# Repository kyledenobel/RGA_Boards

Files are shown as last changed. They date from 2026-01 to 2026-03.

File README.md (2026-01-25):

# RGA_Boards
PCB Board design and development for RGA (Recording Guitar Amplifier)

## Issues and Organization
After completing an issue for board design, please mark as resolved and mention your branch/merge and create another issue for fabrication with the milestone "All Boards Have Been Fabricated" linked to the issue.
Similarly, after fabrication is finished, make an issue for testing with the milestone "All Boards Have Been Tested" linked to the issue.

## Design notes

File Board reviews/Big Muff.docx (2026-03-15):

# Kyle

## Schematic

1) Need to change connector to analog controller

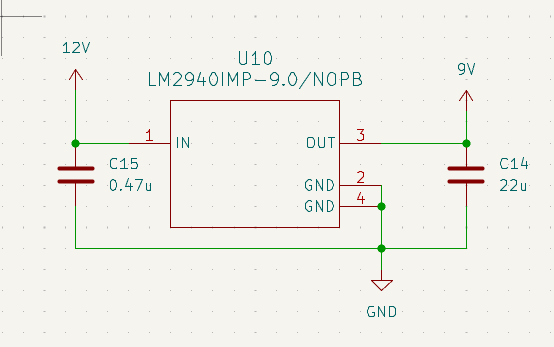
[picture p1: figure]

2) Can Big Muff run on 12 V? can save on component parts if we use 12 instead of 9

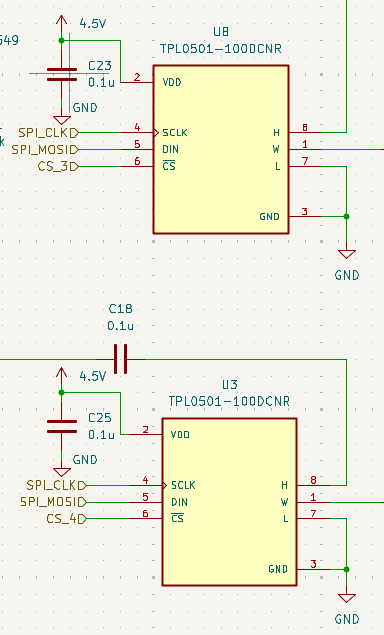
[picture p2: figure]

3) If these are to take more of one and less of another, we use just 1 CS and connect the analog signals opposite of each other. One is H->W->L and the other is L->W->H. When we send the same message, to both in this configuration, they will automatically be opposites of each other.

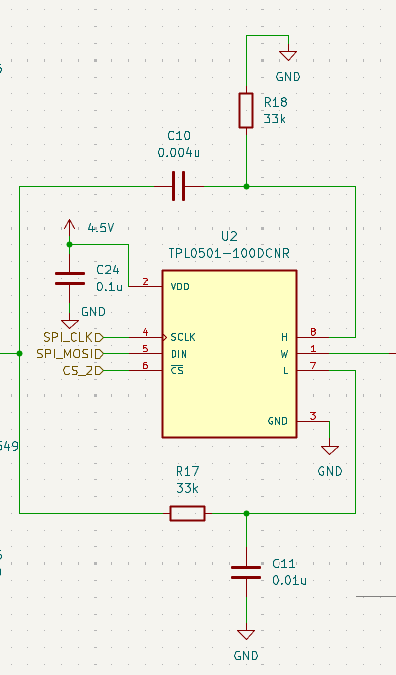
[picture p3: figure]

4) Is decoupling needed on the lower signal?

## Layout

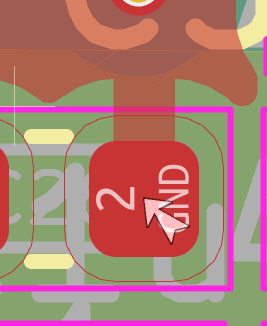
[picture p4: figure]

1) If we care about thermal relief

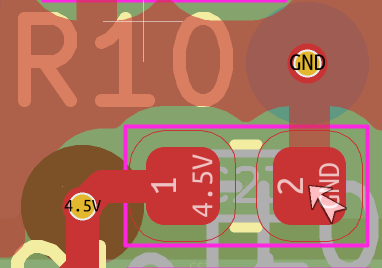
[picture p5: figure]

2) thermal relief

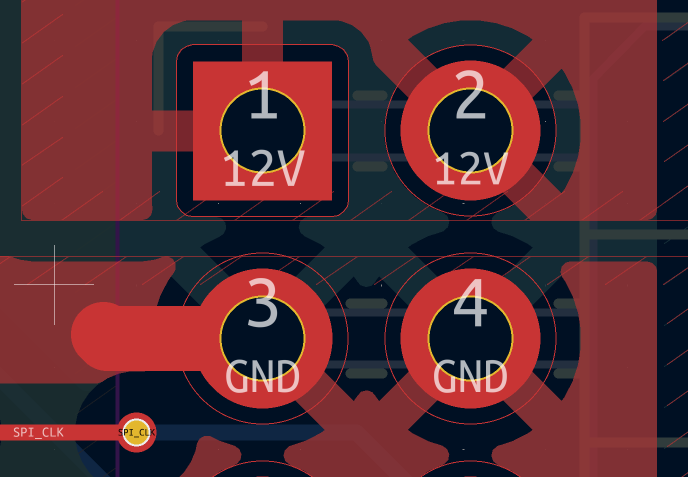
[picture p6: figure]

3) track just chilling. Not connected to anything.

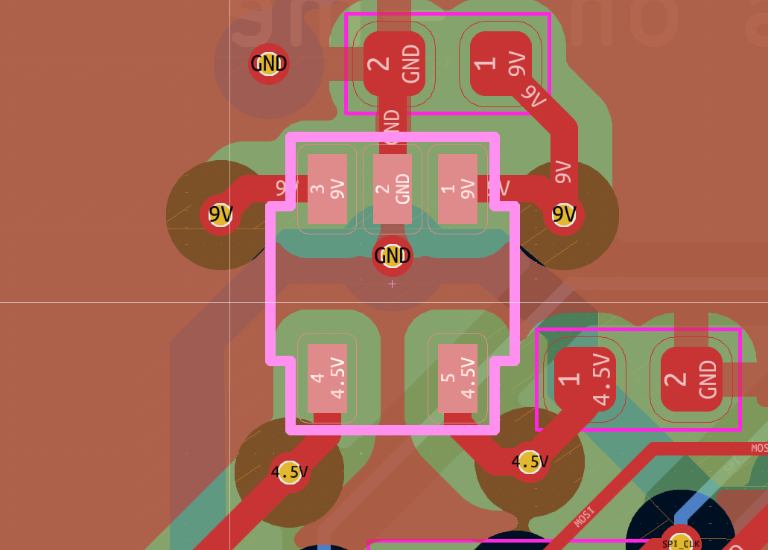
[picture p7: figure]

Gonna need way more vias for that 4.5V plane connection

Big Muff Review

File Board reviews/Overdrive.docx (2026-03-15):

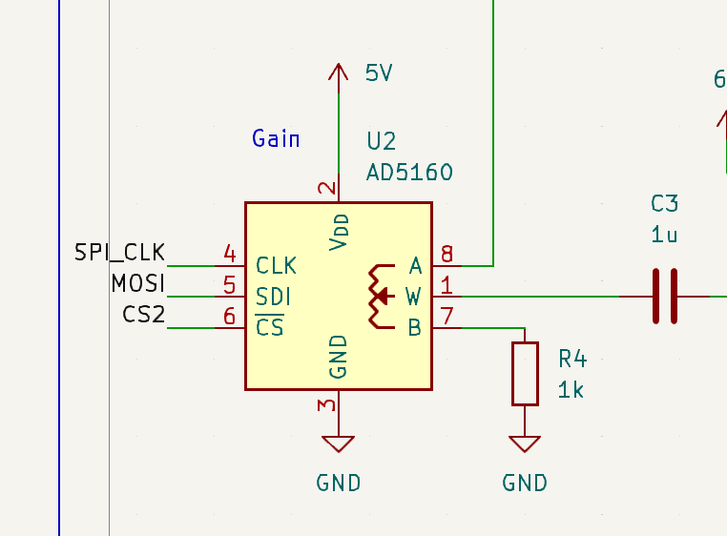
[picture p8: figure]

Add decoupling capacitors to U2 and U5

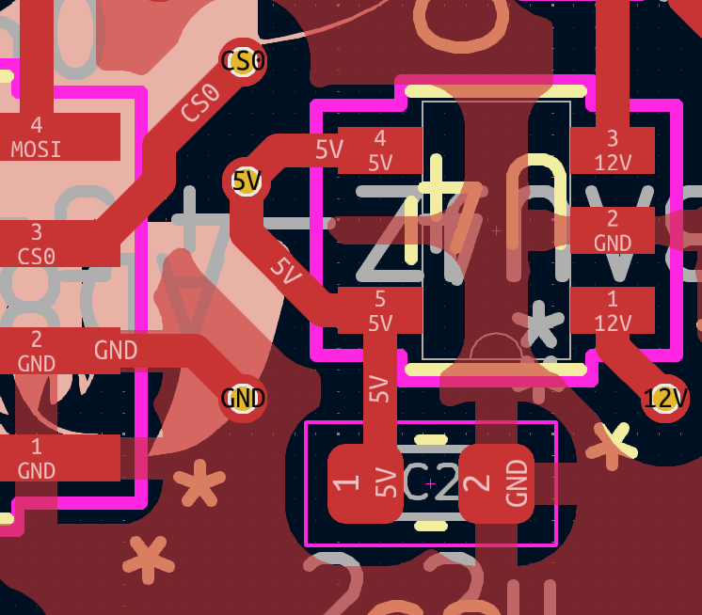
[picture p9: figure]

Add more vias to connect 5V on top layer to 5V plane on 3rd layer

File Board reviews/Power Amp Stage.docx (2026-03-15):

# Kyle

## Schematic

1) No Resistor Values??

## Layout

1) Any reason to flip GND and POWER planes for In2 and B planes? In2 has 24V and GND zones and B has -24V and GND zones. Why not make 1 a purely power and the other purely GND?

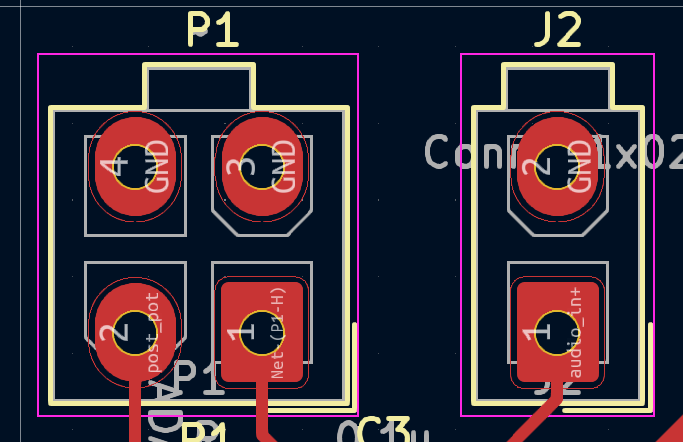
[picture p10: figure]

Ground should be bottom pins. Pins 1 and 2 on the left and Pin 1 on the right should be GND

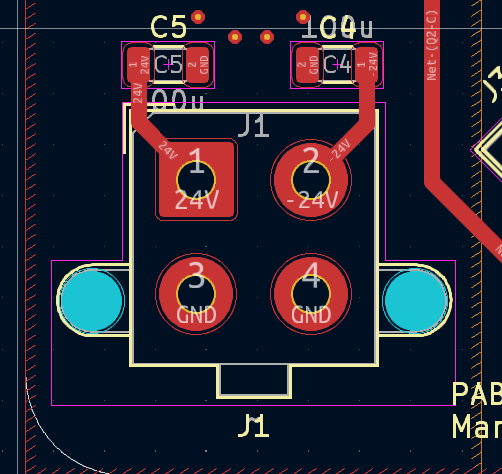
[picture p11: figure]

Same here

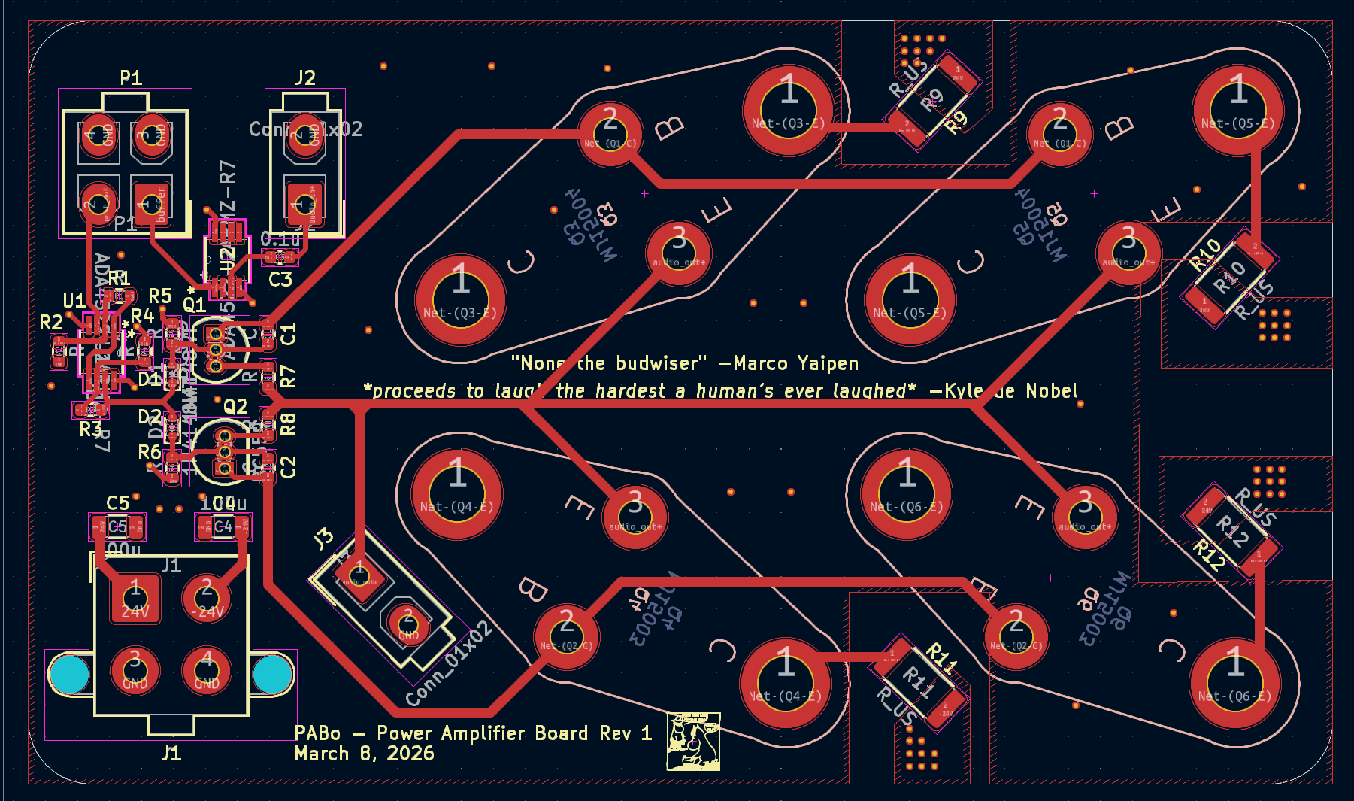
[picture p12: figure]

Moving the connector *might* improve signal quality, because it is now at the end of the signal githupath

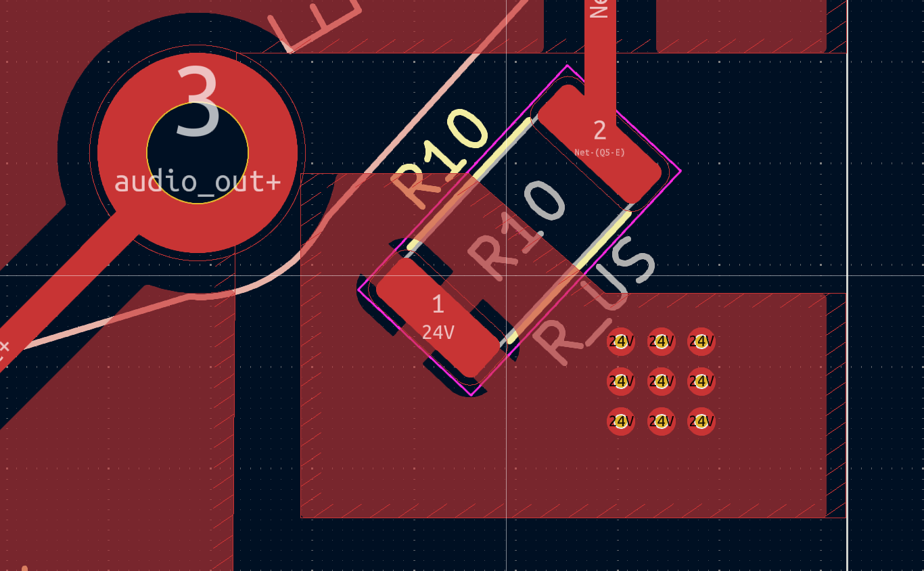
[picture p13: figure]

Thermal reliefs too small for high current carrying paths. Make the connections solid instead. Add more vias to connect the layers.

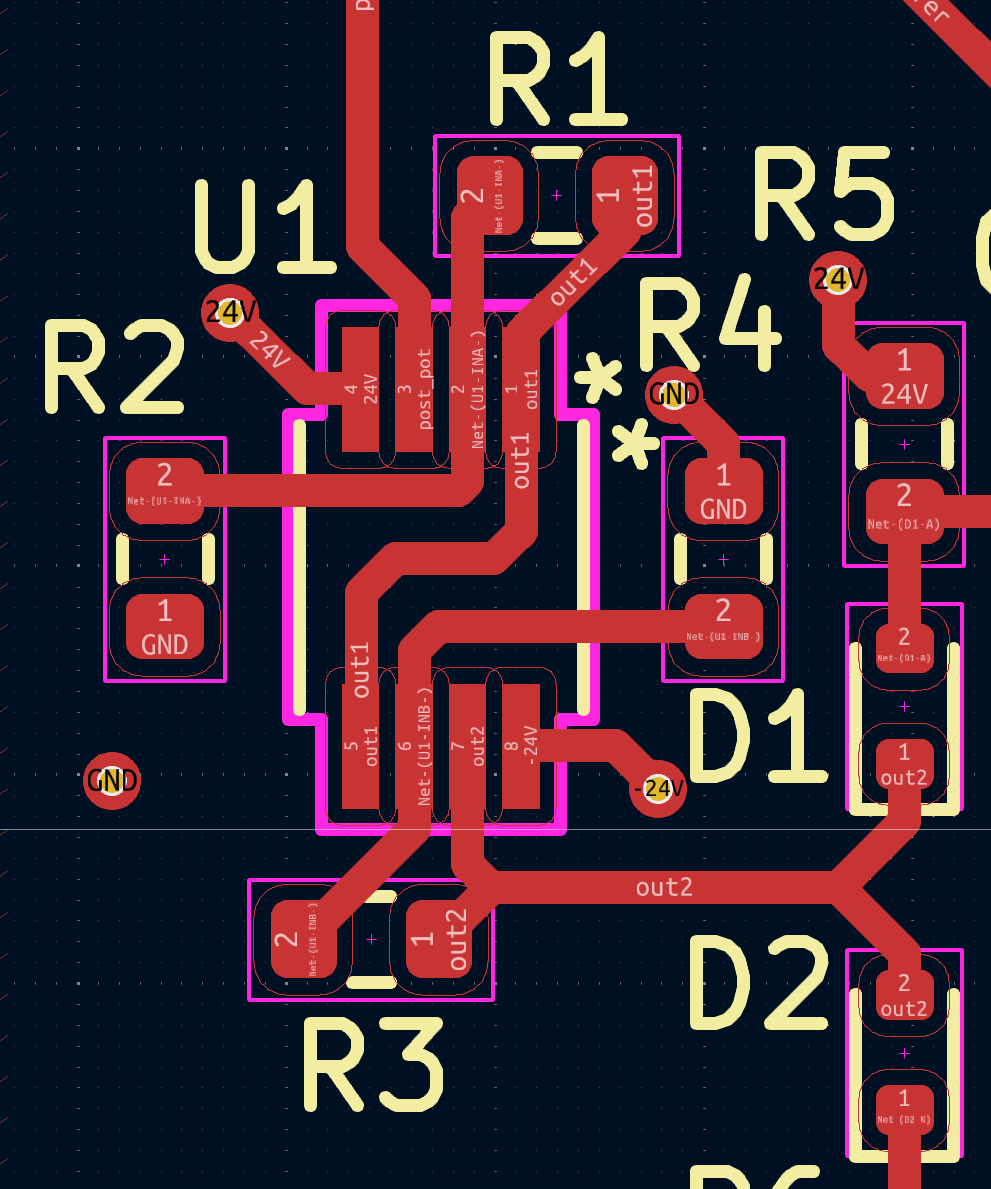
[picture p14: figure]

Move components

Power Amp Stage Review

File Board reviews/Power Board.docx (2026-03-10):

# Kyle

## Schematic

Not finished. Need +/- 24 V supply

## Layout

Power Board Review

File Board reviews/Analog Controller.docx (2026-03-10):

# Kyle

## Schematic Comments

No comments. Looks good.

## Layout Comments

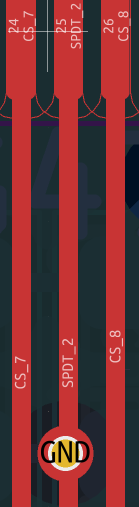
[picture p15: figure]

Shorted SPDT_2 to GND

Analog Controller Board Review

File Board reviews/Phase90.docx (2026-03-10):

# Kyle

## Layout

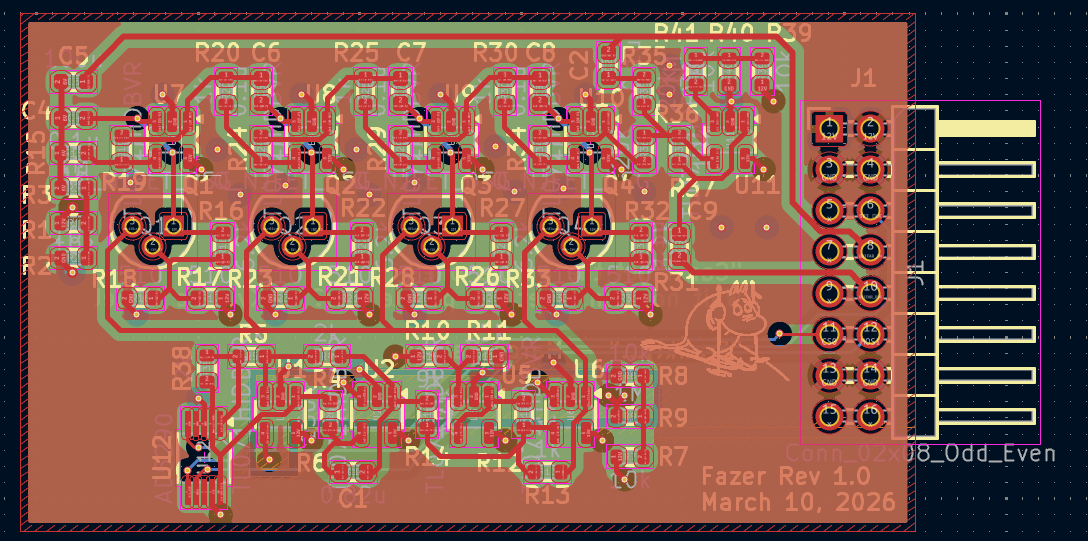
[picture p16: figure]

1) This won’t be able to slide into anything bc of how close things are to the edge. We might need to move the oscillator to the far left and shift the phase shifting down more towards the center of the board.
2) In general, there are a lot of clearance violations, and not all are due to footprints. I think that some routing could be redone to avoid these (there is definitely space to do so around some of these violations).

Phase 90 Review

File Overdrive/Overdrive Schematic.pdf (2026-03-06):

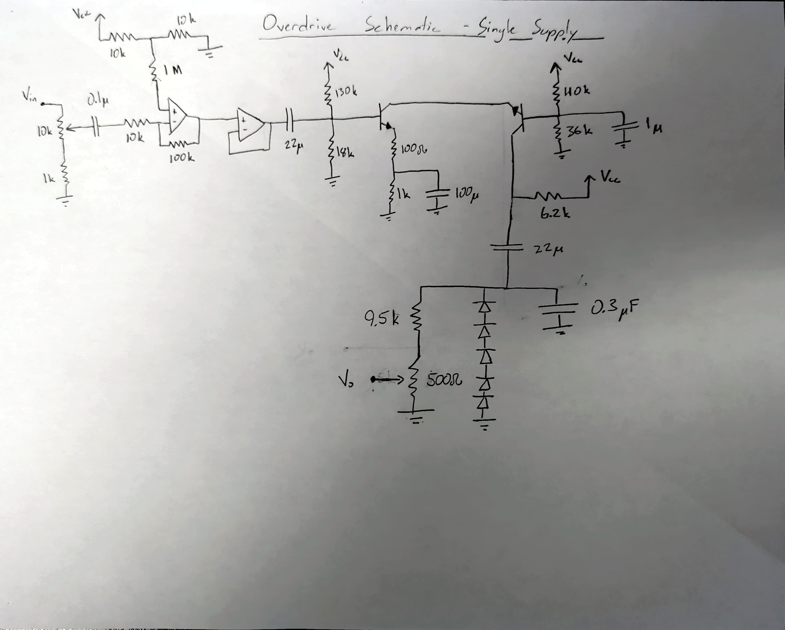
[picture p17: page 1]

q_5k

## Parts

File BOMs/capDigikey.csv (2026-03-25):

Index | Quantity | Part Number | Manufacturer Part Number | Description | Customer Reference | Available | Backorder | Unit Price | Extended Price USD
1 | 150 | 13-CC0603MPY5V9BB104CT-ND | CC0603MPY5V9BB104 | CAP CER 0.1UF 50V Y5V 0603 |  | 150 | 0 | 0.01990 | 2.99
2 | 10 | 399-C0603C103K5RACTUCT-ND | C0603C103K5RACTU | CAP CER 10000PF 50V X7R 0603 |  | 10 | 0 | 0.00900 | 0.09
3 | 10 | 399-C0603C471J5GACTUCT-ND | C0603C471J5GACTU | CAP CER 470PF 50V C0G/NP0 0603 |  | 10 | 0 | 0.04900 | 0.49
4 | 3 | 587-3170-1-ND | UMK107B7474KA-TR | CAP CER 0.47UF 50V X7R 0603 |  | 3 | 0 | 0.15000 | 0.45
5 | 10 | 490-7203-1-ND | GRM188R61E475KE11D | CAP CER 4.7UF 25V X5R 0603 |  | 10 | 0 | 0.03800 | 0.38
6 | 3 | 445-174426-1-ND | CGA3E3X7R1H334K080AB | CAP CER 0.33UF 50V X7R 0603 |  | 3 | 0 | 0.22000 | 0.66
7 | 3 | 13-CC0603KRX7R7BB824CT-ND | CC0603KRX7R7BB824 | CAP CER 0.82UF 16V X7R 0603 |  | 3 | 0 | 0.11000 | 0.33
8 | 10 | 399-C0603C102K5RACTUCT-ND | C0603C102K5RACTU | CAP CER 1000PF 50V X7R 0603 |  | 10 | 0 | 0.00900 | 0.09
9 | 10 | 1292-1542-1-ND | 0603N680J500CT | CAP CER 68PF 50V C0G/NP0 0603 |  | 10 | 0 | 0.02000 | 0.20
10 | 10 | 1276-1063-1-ND | CL10B473KB8NNNC | CAP CER 0.047UF 50V X7R 0603 |  | 10 | 0 | 0.02900 | 0.29
11 | 10 | 490-GCM1885C2A911FA16DCT-ND | GCM1885C2A911FA16D | CAP CER 910PF 100V C0G/NP0 0603 |  | 10 | 0 | 0.09000 | 0.90
12 | 10 | 490-9669-1-ND | GRM1885C1H472JA01D | CAP CER 4700PF 50V C0G/NP0 0603 |  | 10 | 0 | 0.06000 | 0.60
13 | 10 | 720-VJ0603Y681KXACW1BCCT-ND | VJ0603Y681KXACW1BC | CAP CER 680PF 50V X7R 0603 |  | 10 | 0 | 0.05000 | 0.50
14 | 10 | 399-C0603C221K5RACTUCT-ND | C0603C221K5RACTU | CAP CER 220PF 50V X7R 0603 |  | 10 | 0 | 0.04000 | 0.40
15 | 2 | 490-GRM21BR60G107ME11KCT-ND | GRM21BR60G107ME11K | CAP CER 100UF 4V X5R 0805 |  | 2 | 0 | 0.53000 | 1.06
16 | 12 | 490-12737-1-ND | GRM188R61E106MA73J | CAP CER 10UF 25V X5R 0603 |  | 12 | 0 | 0.14200 | 1.70
17 | 100 | 587-3247-1-ND | UMK107AB7105KA-T | CAP CER 1UF 50V X7R 0603 |  | 100 | 0 | 0.02900 | 2.90
18 | 10 | 490-10731-1-ND | GRM188R61E225KA12D | CAP CER 2.2UF 25V X5R 0603 |  | 10 | 0 | 0.04900 | 0.49
19 | 12 | 478-KGM15CR51C226MTCT-ND | 0603YD226MAT2A | CAP CER 22UF 16V X5R 0603 |  | 12 | 0 | 0.29700 | 3.56

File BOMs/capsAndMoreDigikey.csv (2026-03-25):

Index | Quantity | Part Number | Manufacturer Part Number | Description | Customer Reference | Available | Backorder | Unit Price | Extended Price USD
1 | 150 | 13-CC0603MPY5V9BB104CT-ND | CC0603MPY5V9BB104 | CAP CER 0.1UF 50V Y5V 0603 |  | 150 | 0 | 0.01990 | 2.99
2 | 10 | 399-C0603C103K5RACTUCT-ND | C0603C103K5RACTU | CAP CER 10000PF 50V X7R 0603 |  | 10 | 0 | 0.00900 | 0.09
3 | 10 | 399-C0603C471J5GACTUCT-ND | C0603C471J5GACTU | CAP CER 470PF 50V C0G/NP0 0603 |  | 10 | 0 | 0.04900 | 0.49
4 | 3 | 587-3170-1-ND | UMK107B7474KA-TR | CAP CER 0.47UF 50V X7R 0603 |  | 3 | 0 | 0.15000 | 0.45
5 | 10 | 490-7203-1-ND | GRM188R61E475KE11D | CAP CER 4.7UF 25V X5R 0603 |  | 10 | 0 | 0.03800 | 0.38
6 | 3 | 445-174426-1-ND | CGA3E3X7R1H334K080AB | CAP CER 0.33UF 50V X7R 0603 |  | 3 | 0 | 0.22000 | 0.66
7 | 3 | 13-CC0603KRX7R7BB824CT-ND | CC0603KRX7R7BB824 | CAP CER 0.82UF 16V X7R 0603 |  | 3 | 0 | 0.11000 | 0.33
8 | 10 | 399-C0603C102K5RACTUCT-ND | C0603C102K5RACTU | CAP CER 1000PF 50V X7R 0603 |  | 10 | 0 | 0.00900 | 0.09
9 | 10 | 1292-1542-1-ND | 0603N680J500CT | CAP CER 68PF 50V C0G/NP0 0603 |  | 10 | 0 | 0.02000 | 0.20
10 | 10 | 1276-1063-1-ND | CL10B473KB8NNNC | CAP CER 0.047UF 50V X7R 0603 |  | 10 | 0 | 0.02900 | 0.29
11 | 10 | 490-GCM1885C2A911FA16DCT-ND | GCM1885C2A911FA16D | CAP CER 910PF 100V C0G/NP0 0603 |  | 10 | 0 | 0.09000 | 0.90
12 | 10 | 490-9669-1-ND | GRM1885C1H472JA01D | CAP CER 4700PF 50V C0G/NP0 0603 |  | 10 | 0 | 0.06000 | 0.60
13 | 10 | 720-VJ0603Y681KXACW1BCCT-ND | VJ0603Y681KXACW1BC | CAP CER 680PF 50V X7R 0603 |  | 10 | 0 | 0.05000 | 0.50
14 | 10 | 399-C0603C221K5RACTUCT-ND | C0603C221K5RACTU | CAP CER 220PF 50V X7R 0603 |  | 10 | 0 | 0.04000 | 0.40
15 | 2 | 490-GRM21BR60G107ME11KCT-ND | GRM21BR60G107ME11K | CAP CER 100UF 4V X5R 0805 |  | 2 | 0 | 0.53000 | 1.06
16 | 12 | 490-12737-1-ND | GRM188R61E106MA73J | CAP CER 10UF 25V X5R 0603 |  | 12 | 0 | 0.14200 | 1.70
17 | 100 | 587-3247-1-ND | UMK107AB7105KA-T | CAP CER 1UF 50V X7R 0603 |  | 100 | 0 | 0.02900 | 2.90
18 | 10 | 490-10731-1-ND | GRM188R61E225KA12D | CAP CER 2.2UF 25V X5R 0603 |  | 10 | 0 | 0.04900 | 0.49
19 | 12 | 478-KGM15CR51C226MTCT-ND | 0603YD226MAT2A | CAP CER 22UF 16V X5R 0603 |  | 12 | 0 | 0.29700 | 3.56
20 | 10 | 846-1198-1-ND | SML-D13M8WT86 | LED GREEN DIFFUSED 1608 SMD |  | 10 | 0 | 0.13200 | 1.32
21 | 14 | 1N4148W-13FDICT-ND | 1N4148W-13-F | DIODE STANDARD 100V 150MA SOD123 |  | 14 | 0 | 0.06000 | 0.84
22 | 10 | 1N4148WTCT-ND | 1N4148WT | DIODE STANDARD 75V 200MA SOD523F |  | 10 | 0 | 0.06900 | 0.69
23 | 2 | 36-3568-ND | 3568 | FUSE HOLDER BLADE 500V 30A PCB |  | 2 | 0 | 1.25000 | 2.50
24 | 25 | WM3800-ND | 0039281023 | CONN HEADER VERT 2POS |  | 25 | 0 | 0.48300 | 12.08
25 | 25 | WM3700-ND | 0039012020 | CONN RCPT HSG 2POS DUAL |  | 25 | 0 | 0.20000 | 5.00
26 | 6 | S7111-ND | PPPC082LFBN-RC | CONN HDR 16POS 0.1 GOLD PCB |  | 6 | 0 | 0.85000 | 5.10
27 | 10 | WM16836-ND | 0768290102 | CONN HEADER VERT 2POS |  | 10 | 0 | 0.88700 | 8.87
28 | 10 | WM10385-ND | 1716920102 | CONN RCPT HSG 2POS MEGA-FIT |  | 10 | 0 | 0.34900 | 3.49
29 | 2 | WM4713-ND | 0430451812 | CONN HEADER VERT 18POS 3MM |  | 2 | 0 | 1.95000 | 3.90
30 | 4 | WM26557-ND | 2068320801 | CONN HEADER VERT 8POS 3MM |  | 4 | 0 | 1.98000 | 7.92
31 | 4 | WM26545-ND | 2064610800 | CONN RCPT HSG 8POS 3.00MM |  | 4 | 0 | 0.60000 | 2.40
32 | 1 | 1951-2505-ND | TMV 1205D | DC DC CONVERTER +/-5V 1W |  | 1 | 0 | 6.40000 | 6.40
33 | 2 | 945-R-78K5.0-0.5-ND | R-78K5.0-0.5 | 0.5A DC/DC-CONVERTER 'INNOLINE' |  | 2 | 0 | 2.79000 | 5.58
34 | 1 | 1866-3063-ND | IRM-60-12 | AC/DC CONVERTER 12V 60W |  | 1 | 0 | 15.00000 | 15.00
35 | 10 | 4878-BC549CCT-ND | BC549C | TRANS NPN 30V 0.1A TO-92 |  | 10 | 0 | 0.08300 | 0.83
36 | 2 | 4878-BC559CCT-ND | BC559C | TRANS PNP 30V 0.1A TO-92 |  | 2 | 0 | 0.14000 | 0.28

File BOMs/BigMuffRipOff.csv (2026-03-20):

Reference | Qty | Value | DNP | Exclude from BOM | Exclude from Board | Footprint | Datasheet
C1,C3,C4,C6,C7,C8,C12,C13,C17,C18,C21,C22,C23,C24,C25,C26 | 16 | 0.1u |  |  |  | Capacitor_SMD:C_0603_1608Metric | ~
C2,C5,C9 | 3 | 470p |  |  |  | Capacitor_SMD:C_0603_1608Metric | ~
C10 | 1 | 0.004u |  |  |  | Capacitor_SMD:C_0603_1608Metric | ~
C11 | 1 | 0.01u |  |  |  | Capacitor_SMD:C_0603_1608Metric | ~
C14,C16,C27 | 3 | 22u |  |  |  | Capacitor_SMD:C_0603_1608Metric | ~
C15 | 1 | 0.47u |  |  |  | Capacitor_SMD:C_0603_1608Metric | ~
C19,C20 | 2 | 2.2u |  |  |  | Capacitor_SMD:C_0603_1608Metric | ~
C28,C29,C30,C31 | 4 | 1u |  |  |  | Capacitor_SMD:C_0603_1608Metric | ~
CR3,CR4 | 2 | 1N4148W-13-F |  |  |  | 284867-E-footprint:SOD123_DIO | 1N4148W-13-F
J1 | 1 | Conn_02x08_Odd_Even |  |  |  | Connector_PinHeader_2.54mm:PinHeader_2x08_P2.54mm_Horizontal | ~
Q1,Q2,Q3,Q4 | 4 | BC549 |  |  |  | Package_TO_SOT_THT:TO-92_Inline | https://www.digikey.com/en/products/detail/onsemi/BC549/974184
R1,R17,R18 | 3 | 33k |  |  |  | Resistor_SMD:R_0603_1608Metric | ~
R2,R9,R14,R19 | 4 | 100k |  |  |  | Resistor_SMD:R_0603_1608Metric | ~
R3,R11,R13,R20 | 4 | 470k |  |  |  | Resistor_SMD:R_0603_1608Metric | ~
R4,R8 | 2 | 8.2k |  |  |  | Resistor_SMD:R_0603_1608Metric | ~
R5,R12,R15,R22 | 4 | 12k |  |  |  | Resistor_SMD:R_0603_1608Metric | ~
R6,R10,R16 | 3 | 100 |  |  |  | Resistor_SMD:R_0603_1608Metric | ~
R7 | 1 | 560 |  |  |  | Resistor_SMD:R_0603_1608Metric | ~
R21 | 1 | 2.7k |  |  |  | Resistor_SMD:R_0603_1608Metric | ~
R23,R25 | 2 | 10k |  |  |  | Resistor_SMD:R_0603_1608Metric | ~
R24 | 1 | 20k |  |  |  | Resistor_SMD:R_0603_1608Metric | ~
R26,R27,R28,R29 | 4 | 500k |  |  |  | Resistor_SMD:R_0603_1608Metric | ~
U1,U2,U3,U8 | 4 | TPL0501-100DCNR |  |  |  | 284867-E-footprint:SOT65P280X145-8N | https://www.digikey.com/en/products/detail/texas-instruments/TPL0501-100DCNR/2755770
U4,U5,U7,U9 | 4 | TL071HIDBVR |  |  |  | 284867-E-footprint:SOT23_DBV_5_TEX | https://www.digikey.com/en/products/detail/texas-instruments/TL071HIDBVR/14835784
U6 | 1 | ADP7118AUJZ-4.5-R7 |  |  |  | 284867-E-footprint:UJ-5_ADI | https://www.digikey.com/en/products/detail/analog-devices-inc/ADP7118AUJZ-4-5-R7/6599734
U10 | 1 | LM2940IMP-9.0/NOPB |  |  |  | GTSR_KiCAD_Footprints:DCY0004A_N | https://www.ti.com/lit/gpn/lm2940-n

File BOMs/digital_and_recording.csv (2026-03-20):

Reference | Qty | Value | DNP | Exclude from BOM | Exclude from Board | Footprint | Datasheet
C1,C8 | 2 | 1u |  |  |  | Capacitor_SMD:C_0603_1608Metric | ~
C2,C3,C4,C5,C6,C7,C14 | 7 | 0.1u |  |  |  | Capacitor_SMD:C_0603_1608Metric | ~
C9,C10,C13 | 3 | 10u |  |  |  | Capacitor_SMD:C_0603_1608Metric | ~
C11,C12 | 2 | 4.7u |  |  |  | Capacitor_SMD:C_0603_1608Metric | ~
H1,H2,H3,H4 | 4 | MountingHole |  | Excluded from BOM |  | MountingHole:MountingHole_2.7mm_M2.5 | ~
J1 | 1 | Headphones |  |  |  | CONN_SD-5566-002_02_MOL | https://www.molex.com/en-us/products/part-detail-pdf/39281023?display=pdf
J2 | 1 | Screen |  |  |  | GTSR_KiCAD_Footprints:MOLEX_2068320801 | https://www.molex.com/pdm_docs/sd/2068320801_sd.pdf
J3 | 1 | USB_Breakout |  |  |  | Connector_PinHeader_2.54mm:PinHeader_1x04_P2.54mm_Vertical | ~
J4 | 1 | Joystick |  |  |  | GTSR_KiCAD_Footprints:MOLEX_2068320801 | https://www.molex.com/pdm_docs/sd/2068320801_sd.pdf
J6,J7 | 2 | MINIFIT-2-VERT |  |  |  | Connector_Molex:Molex_Mini-Fit_Jr_5566-02A_2x01_P4.20mm_Vertical
J8 | 1 | MINIFIT-2-VERT |  |  |  | Connector_Molex:Molex_Mega-Fit_76829-0102_2x01_P5.70mm_Vertical
PS1 | 1 | TMV_1205D |  |  |  | Kyle's Footprints:CONV_TMV_1205D | https://www.mouser.com/ProductDetail/TRACO-Power/TMV-1205D?qs=ckJk83FOD0UYyrZkxHtyBw%3D%3D
PS2,PS3 | 2 | R-78K5.0-0.5 |  |  |  | Kyle's Footprints:CONV_R-78K5.0-0.5 | https://www.mouser.com/ProductDetail/RECOM-Power/R-78K5.0-0.5?qs=Jm2GQyTW%2Fbjx2N4NpeyrMA%3D%3D
R1,R2 | 2 | R |  |  |  | Resistor_SMD:R_0603_1608Metric | ~
R3,R4,R5,R6 | 4 | 0 |  |  |  | Resistor_SMD:R_0603_1608Metric | ~
R7 | 1 | 240 |  |  |  | Resistor_SMD:R_0603_1608Metric | ~
U1 | 1 | Daisy_Seed |  |  |  | Kyle's Footprints:DAISY_SEED | https://static1.squarespace.com/static/58d03fdc1b10e3bf442567b8/t/6227e6236f02fb68d1577146/1646781988478/Daisy_Seed_datasheet_v1.0.3.pdf
U2 | 1 | Daisy_Seed_Recording |  |  |  | Kyle's Footprints:DAISY_SEED | https://static1.squarespace.com/static/58d03fdc1b10e3bf442567b8/t/6227e6236f02fb68d1577146/1646781988478/Daisy_Seed_datasheet_v1.0.3.pdf
U3 | 1 | Bypass 2 |  |  |  | Kyle's Footprints:SOT65P280X145-8N | https://www.ti.com/lit/ds/symlink/ts12a12511.pdf?HQS=dis-dk-null-digikeymode-dsf-pf-null-wwe&ts=1771720391319
U4 | 1 | Bypass 1 |  |  |  | Kyle's Footprints:SOT65P280X145-8N | https://www.ti.com/lit/ds/symlink/ts12a12511.pdf?HQS=dis-dk-null-digikeymode-dsf-pf-null-wwe&ts=1771720391319
U5 | 1 | Output Select |  |  |  | Kyle's Footprints:SOT65P280X145-8N | https://www.ti.com/lit/ds/symlink/ts12a12511.pdf?HQS=dis-dk-null-digikeymode-dsf-pf-null-wwe&ts=1771720391319

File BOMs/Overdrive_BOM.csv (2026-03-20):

Reference | Qty | Value | DNP | Exclude from BOM | Exclude from Board | Footprint | Datasheet
C1,C2 | 2 | 2.2u |  |  |  | Capacitor_SMD:C_0603_1608Metric | ~
C3,C6,C9,C11,C12,C13,C14,C15 | 8 | 1u |  |  |  | Capacitor_SMD:C_0603_1608Metric | ~
C4,C7,C10 | 3 | 22u |  |  |  | Capacitor_SMD:C_0603_1608Metric | ~
C5 | 1 | 100u |  |  |  | Capacitor_SMD:C_1206_3216Metric | ~
C8 | 1 | 0.3u |  |  |  | Capacitor_SMD:C_0603_1608Metric | ~
D1,D2,D3,D4,D5 | 5 | 1N4148W |  |  |  | Diode_SMD:D_SOD-123 | https://www.vishay.com/docs/85748/1n4148w.pdf
J1 | 1 | Conn_02x08_Odd_Even |  |  |  | Connector_PinHeader_2.54mm:PinHeader_2x08_P2.54mm_Horizontal | ~
Q1,Q2 | 2 | 2N3904 |  |  |  | Package_TO_SOT_THT:TO-92_Inline | https://www.onsemi.com/pub/Collateral/2N3903-D.PDF
R1,R2,R5 | 3 | 10k |  |  |  | Resistor_SMD:R_0603_1608Metric | ~
R3 | 1 | 1M |  |  |  | Resistor_SMD:R_0603_1608Metric | ~
R4,R10 | 2 | 1k |  |  |  | Resistor_SMD:R_0603_1608Metric | ~
R6 | 1 | 100k |  |  |  | Resistor_SMD:R_0603_1608Metric | ~
R7 | 1 | 130k |  |  |  | Resistor_SMD:R_0603_1608Metric | ~
R8 | 1 | 18k |  |  |  | Resistor_SMD:R_0603_1608Metric | ~
R9 | 1 | 100 |  |  |  | Resistor_SMD:R_0603_1608Metric | ~
R11 | 1 | 40k |  |  |  | Resistor_SMD:R_0603_1608Metric | ~
R12 | 1 | 36k |  |  |  | Resistor_SMD:R_0603_1608Metric | ~
R13 | 1 | 6.2k |  |  |  | Resistor_SMD:R_0603_1608Metric | ~
R14 | 1 | 9k |  |  |  | Resistor_SMD:R_0603_1608Metric | ~
U1,U3,U6 | 3 | TL071HIDBVR |  |  |  | TL071:TL071HIDBVR | https://www.ti.com/lit/gpn/tl071h
U2 | 1 | AD5160 |  |  |  | Package_TO_SOT_SMD:SOT-23-8 | https://www.analog.com/media/en/technical-documentation/data-sheets/AD5160.pdf
U4 | 1 | ADP7118AUJZ-4.5-R7 |  |  |  | ADP7118AUJZ-4-5-R7:UJ-5_ADI | https://www.analog.com/media/en/technical-documentation/data-sheets/adp7118.pdf
U5 | 1 | AD8400ARZ1 |  |  |  | footprints:R_8_ADI | https://www.digikey.com/en/products/detail/analog-devices-inc/AD8400ARZ1-REEL/994213

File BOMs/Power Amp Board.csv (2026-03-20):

Reference | Qty | Value | DNP | Exclude from BOM | Exclude from Board | Footprint | Datasheet
C1,C2 | 2 | C |  |  |  | Capacitor_SMD:C_0603_1608Metric | ~
C3 | 1 | 0.1u |  |  |  | Capacitor_SMD:C_0603_1608Metric | ~
C4,C5 | 2 | 100u |  |  |  | Capacitor_SMD:C_1206_3216Metric | ~
D1,D2 | 2 | 1N4148WT |  |  |  | Diode_SMD:D_SOD-523 | https://www.diodes.com/assets/Datasheets/ds30396.pdf
J1 | 1 | ~ |  |  |  | Connector_Molex:Molex_Mega-Fit_76829-0004_2x02_P5.70mm_Vertical | ~
J2,J3 | 2 | Conn_01x02 |  |  |  | Connector_Molex:Molex_Mini-Fit_Jr_5566-02A_2x01_P4.20mm_Vertical | ~
P1 | 1 | ~ |  |  |  | Connector_Molex:Molex_Mini-Fit_Jr_5566-04A_2x02_P4.20mm_Vertical
Q1 | 1 | BC549 |  |  |  | Package_TO_SOT_THT:TO-92_Inline | https://www.onsemi.com/pub/Collateral/BC550-D.pdf
Q2 | 1 | BC559 |  |  |  | Package_TO_SOT_THT:TO-92_Inline | https://www.onsemi.com/pub/Collateral/BC556BTA-D.pdf
Q3,Q5 | 2 | MJ15004 |  |  |  | Transistor_Power:MJ15000 | https://www.digikey.com/en/products/detail/good-ark-semiconductor/MJ15004/24613137
Q4,Q6 | 2 | MJ15003 |  |  |  | Transistor_Power:MJ15000 | https://www.digikey.com/en/products/detail/good-ark-semiconductor/MJ15003/24613238
R1,R3 | 2 | 100k |  |  |  | Resistor_SMD:R_0603_1608Metric | ~
R2,R4,R5,R6 | 4 | 10k |  |  |  | Resistor_SMD:R_0603_1608Metric | ~
R7,R8 | 2 | 100 |  |  |  | Resistor_SMD:R_0603_1608Metric | ~
R9,R10,R11,R12 | 4 | 4.7 |  |  |  | Resistor_SMD:R_2512_6332Metric | https://www.digikey.com/en/products/detail/susumu/CPA2512Q4R70FS-T10/1935788
U1,U2 | 2 | ADA4522-2ARMZ-R7 |  |  |  | GTSR_KiCAD_Footprints:RM-8_ADI | https://www.digikey.com/en/products/detail/analog-devices-inc/ADA4522-2ARMZ-R7/5268023

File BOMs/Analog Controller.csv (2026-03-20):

Reference | Qty | Value | DNP | Exclude from BOM | Footprint | Product Link
C1,C22,C23,C24,C25,C28,C29 | 7 | 0.1u |  |  | Resistor_SMD:R_0603_1608Metric_Pad0.98x0.95mm_HandSolder | https://www.digikey.com/en/products/detail/yageo/CC0603MPY5V9BB104/21285977?gclsrc=aw.ds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
C2 | 1 | 1u |  |  | Capacitor_SMD:C_0603_1608Metric | https://www.digikey.com/en/products/detail/kemet/C0603C104K8PACTU/8572573?gclsrc=aw.ds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
C4,C5,C6,C7,C8,C9,C10,C11,C12,C13,C14,C15,C16,C17,C18 | 15 | 100n |  |  | Resistor_SMD:R_0603_1608Metric_Pad0.98x0.95mm_HandSolder | https://www.digikey.com/en/products/detail/yageo/CC0603MPY5V9BB104/21285977?gclsrc=aw.ds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
C21 | 1 | 10u |  |  | Resistor_SMD:R_0603_1608Metric_Pad0.98x0.95mm_HandSolder | https://www.digikey.com/en/products/detail/murata-electronics/GRM188R61E106MA73J/5797706?gclsrc=aw.ds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
C26 | 1 | 10n |  |  | Resistor_SMD:R_0603_1608Metric_Pad0.98x0.95mm_HandSolder | https://www.digikey.com/en/products/detail/kemet/C0603C103K4RECTU/13562110?gclsrc=aw.ds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
C27,C30 | 2 | 1u |  |  | Resistor_SMD:R_0603_1608Metric_Pad0.98x0.95mm_HandSolder | https://www.digikey.com/en/products/detail/kemet/C0603C104K8PACTU/8572573?gclsrc=aw.ds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
D1,D2 | 2 | G |  |  | LED_SMD:LED_0603_1608Metric_Pad1.05x0.95mm_HandSolder | https://www.digikey.com/en/products/detail/rohm-semiconductor/SML-D13M8WT86/5722632?gclsrc=aw.ds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
D3,D4,D5 | 3 | G | DNP | Excluded from BOM | LED_SMD:LED_0603_1608Metric_Pad1.05x0.95mm_HandSolder
H1,H2,H3,H4 | 4 | No. 8 |  |  | MountingHole:MountingHole_3.2mm_M3
J1,J4 | 2 | MINIFIT-2-VERT |  |  | Connector_Molex:Molex_Mini-Fit_Jr_5566-02A_2x01_P4.20mm_Vertical | https://www.digikey.com/en/products/detail/molex/0039281023/61397
J2,J3,J8 | 3 | Conn_02x08_Counter_Clockwise |  |  | Connector_PinSocket_2.54mm:PinSocket_2x08_P2.54mm_Vertical | https://www.digikey.com/en/products/detail/sullins-connector-solutions/PPPC082LFBN-RC/810248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..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
J6 | 1 | MEGAFIT-2-VERT |  |  | Connector_Molex:Molex_Mega-Fit_76829-0102_2x01_P5.70mm_Vertical | https://www.digikey.com/en/products/detail/molex/0768290102/7604320
J7 | 1 | Conn_02x09_Counter_Clockwise |  |  | Connector_Molex:Molex_Micro-Fit_3.0_43045-1812_2x09_P3.00mm_Vertical | https://www.digikey.com/en/products/detail/molex/0430451812/531413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
J10 | 1 | TC2050 |  | Excluded from BOM | Connector:Tag-Connect_TC2050-IDC-FP_2x05_P1.27mm_Vertical
R1,R2,R3 | 3 | 27k |  |  | Resistor_SMD:R_0603_1608Metric_Pad0.98x0.95mm_HandSolder | https://www.digikey.com/en/products/detail/yageo/RC0603FR-1327KL/14287589?gclsrc=aw.ds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
R4,R11,R12,R13 | 4 | 440 |  |  | Resistor_SMD:R_0603_1608Metric_Pad0.98x0.95mm_HandSolder | https://www.digikey.com/en/products/detail/yageo/RC0603FR-10430RL/14287773?gclsrc=aw.ds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
R5 | 1 | 1.2k |  |  | Resistor_SMD:R_0603_1608Metric_Pad0.98x0.95mm_HandSolder | https://www.google.com/aclk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
R6,R7,R8 | 3 | 4.7k |  |  | Resistor_SMD:R_0603_1608Metric_Pad0.98x0.95mm_HandSolder | https://www.google.com/aclk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
R9 | 1 | 240 |  |  | Resistor_SMD:R_0603_1608Metric_Pad0.98x0.95mm_HandSolder | https://www.google.com/aclk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
R14,R15,R16,R17,R18,R19,R20,R21,R23 | 9 | 150 |  |  | Resistor_SMD:R_0603_1608Metric_Pad0.98x0.95mm_HandSolder | https://www.google.com/aclk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
R22 | 1 | 10k |  |  | Resistor_SMD:R_0603_1608Metric_Pad0.98x0.95mm_HandSolder | https://www.google.com/aclk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
RV1,RV2,RV3 | 3 | R_Potentiometer_US | DNP | Excluded from BOM
SW1 | 1 | SW_SPDT | DNP | Excluded from BOM
SW2 | 1 | SW_Omron_B3FS |  |  | Button_Switch_SMD:SW_SPST_Omron_B3FS-101xP | https://www.google.com/aclk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
SW3 | 1 | SW_Push_Open | DNP | Excluded from BOM
SW4 | 1 | SW_SPST |  |  | Button_Switch_SMD:SW_SPST_B3U-1000P | https://www.digikey.com/en/products/detail/omron-electronics-inc-emc-div/B3U-1000P/1534338
U1,U2,U3,U6,U7,U8 | 6 | TS12A12511DCNR |  |  | TS12A12511DCNR:DCN8
U4 | 1 | R-78C3.3-1.0 |  |  | Converter_DCDC:Converter_DCDC_RECOM_R-78E-0.5_THT | https://www.digikey.com/en/products/detail/recom-power/R-78K3.3-1.0/18093033?gclsrc=aw.ds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
U5 | 1 | TMA-1205D |  |  | Converter_DCDC:Converter_DCDC_TRACO_TMA-05xxD_12xxD_Dual_THT | https://www.digikey.com/en/products/detail/traco-power/TMA-1205D/9383352
U11,U12,U13 | 3 | 74LVC1G17 |  |  | Package_TO_SOT_SMD:SOT-23-5 | https://www.digikey.com/en/products/detail/texas-instruments/SN74LVC1G17DBVRG4/4833886?gclsrc=aw.ds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
U14 | 1 | STM32G474RETx |  |  | Package_QFP:LQFP-64_10x10mm_P0.5mm | https://www.digikey.com/en/products/detail/stmicroelectronics/STM32G474RET6/10326780
 |  |  |  |  | minitfit 2 position female part | https://www.digikey.com/en/products/detail/molex/0039012020/61315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
 |  |  |  |  | megafit 2 position female part | https://www.digikey.com/en/products/detail/molex/1716920102/4515271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
 |  |  |  |  | microfit 18 position female part | https://www.digikey.com/en/products/detail/molex/0430251810/12142544?gclsrc=aw.ds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

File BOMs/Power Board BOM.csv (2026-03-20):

Reference | Qty | Value | DNP | Exclude from BOM | Footprint | Product Link
F1 | 1 | Fuse |  |  | Fuse:Fuseholder_Blade_Mini_Keystone_3568 | https://www.digikey.com/en/products/detail/keystone-electronics/3568/2137306?gclsrc=aw.ds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
H1,H2,H3,H4 | 4 | No. 8 |  |  | MountingHole:MountingHole_3.2mm_M3
J1 | 1 | MEGAFIT-2-VERT |  |  | Connector_Molex:Molex_Mega-Fit_76829-0102_2x01_P5.70mm_Vertical | https://www.digikey.com/en/products/detail/molex/0768290102/7604320
J2,J3,J7,J9 | 4 | MINIFIT-2-VERT |  |  | Connector_Molex:Molex_Mini-Fit_Jr_5566-02A_2x01_P4.20mm_Vertical | https://www.digikey.com/en/products/detail/molex/0039281023/61397
J4 | 1 | MEGAFIT-2-VERT |  |  | Connector_Molex:Molex_Mega-Fit_76829-0102_2x01_P5.70mm_Vertical | https://www.digikey.com/en/products/detail/molex/0768290102/7604320
J5 | 1 | Microfit 2 position |  |  | Connector_Molex:Molex_Micro-Fit_3.0_43650-0215_1x02_P3.00mm_Vertical | https://www.google.com/aclk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
J6 | 1 | MEGAFIT-2-VERT |  |  | Connector_Molex:Molex_Mega-Fit_76829-0004_2x02_P5.70mm_Vertical | https://www.digikey.com/en/products/detail/molex/0768290102/7604320
J8 | 1 | pin header 1x02 |  |  | Connector_PinHeader_2.54mm:PinHeader_1x02_P2.54mm_Vertical | https://www.digikey.com/en/products/detail/amphenol-icc-fci-/10129378-902002BLF/7915925?gclsrc=aw.ds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
PS1 | 1 | IRM-60-12 |  |  | Converter_ACDC:Converter_ACDC_MeanWell_IRM-60-xx_THT | https://www.digikey.com/en/products/detail/mean-well-usa-inc/IRM-60-12/7704688
U1 | 1 | AC025-D24 |  |  | GTSR_KiCAD_Footprints:AC025-D15 | https://www.digikey.com/en/products/detail/adam-tech/AC025-D24/22469417

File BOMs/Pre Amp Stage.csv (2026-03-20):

Reference | Qty | Value | DNP | Exclude from BOM | Footprint | Product Link
C1 | 1 | 68p |  |  | Resistor_SMD:R_0603_1608Metric | https://www.digikey.com/en/products/detail/johanson-technology-inc/QSCP251Q680J1GV001T/1561633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..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
C2,C7 | 2 | 10u |  |  | Resistor_SMD:R_0603_1608Metric | https://www.digikey.com/en/products/detail/murata-electronics/GRM188R61E106MA73J/5797706?gclsrc=aw.ds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
C3 | 1 | 47n |  |  | Resistor_SMD:R_0603_1608Metric | https://www.digikey.com/en/products/detail/kemet/C0603C473K5RACTU/2200870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
C4 | 1 | 940p |  |  | Resistor_SMD:R_0603_1608Metric | https://www.digikey.com/en/products/detail/murata-electronics/GCM1885C2A911FA16D/16033413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..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
C5 | 1 | 0.0047u |  |  | Resistor_SMD:R_0603_1608Metric | https://www.digikey.com/en/products/detail/murata-electronics/GRM1885C1H472JA01D/4421616
C6 | 1 | 680p |  |  | Resistor_SMD:R_0603_1608Metric | https://www.digikey.com/en/products/detail/vishay-vitramon/VJ0603Y681KXACW1BC/8306532
C8,C9,C10,C11,C13,C14 | 6 | 1u |  |  | Resistor_SMD:R_0603_1608Metric | https://www.digikey.com/en/products/detail/kemet/C0603C104K8PACTU/8572573?gclsrc=aw.ds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
C12 | 1 | 220p |  |  | Resistor_SMD:R_0603_1608Metric | https://www.digikey.com/en/products/detail/kemet/C0603C221K5RACTU/411073
C15 | 1 | 100u |  |  | Resistor_SMD:R_0805_2012Metric_Pad1.20x1.40mm_HandSolder | https://www.digikey.com/en/products/detail/murata-electronics/GRM21BR60G107ME11K/13544362?gclsrc=aw.ds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
H1,H2,H3,H4 | 4 | MountingHole |  | Excluded from BOM | MountingHole:MountingHole_2.2mm_M2
J1 | 1 | NMJ6HFD2 |  |  | Connector_Audio:Jack_6.35mm_Neutrik_NMJ6HFD2_Horizontal | https://www.google.com/aclk?ae=2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
J2,J3,J5,J6,J7 | 5 | Conn_01x03 |  |  | Connector_Molex:Molex_Micro-Fit_3.0_43650-0315_1x03_P3.00mm_Vertical | https://www.google.com/aclk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
J4,J8 | 2 | MINIFIT-2-VERT |  |  | Connector_Molex:Molex_Mini-Fit_Jr_5566-02A_2x01_P4.20mm_Vertical | https://www.digikey.com/en/products/detail/molex/0039281023/61397
Q1 | 1 | Q_NJFET_DSG |  |  | Package_TO_SOT_THT:TO-92_Inline
R1 | 1 | 499k |  |  | Resistor_SMD:R_0603_1608Metric | https://www.digikey.com/en/products/detail/yageo/AC0603FR-07499KL/12707691?gclsrc=aw.ds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
R2 | 1 | 100 |  |  | Resistor_SMD:R_0603_1608Metric | https://www.digikey.com/en/products/detail/yageo/RC0603FR-13100RL/12756438?gclsrc=aw.ds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
R3 | 1 | 50k |  |  | Resistor_SMD:R_0603_1608Metric | https://www.digikey.com/en/products/detail/vishay-dale-thin-film/PNM0603E5002BST5/2120326
R4,R6,R7,R9 | 4 | 7.5k |  |  | Resistor_SMD:R_0603_1608Metric | https://www.digikey.com/en/products/detail/stackpole-electronics-inc/RMEF0603FT7K50/16840016?gclsrc=aw.ds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
R5,R8 | 2 | 2.7k |  |  | Resistor_SMD:R_0603_1608Metric | https://www.digikey.com/en/products/detail/yageo/RC0603FR-072K7P/22199799?gclsrc=aw.ds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
R10,R11 | 2 | 100k |  |  | Resistor_SMD:R_0603_1608Metric | https://www.digikey.com/en/products/detail/yageo/RC0603FR-13100KL/12756433?gclsrc=aw.ds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
U1,U3,U4 | 3 | TL071HIDBVR |  |  | GTSR_KiCAD_Footprints:TL071 | https://www.digikey.com/en/products/detail/texas-instruments/TL071HIDBVR/14835784
U2 | 1 | TMA-1215D |  |  | Converter_DCDC:Converter_DCDC_TRACO_TMA-05xxD_12xxD_Dual_THT | https://www.digikey.com/en/products/detail/traco-power/TMA-1215D/9383617
 |  |  |  |  | minitfit 2 position female part | https://www.digikey.com/en/products/detail/molex/0039012020/61315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
 |  |  |  |  | microfit 3 position female part | https://www.google.com/aclk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

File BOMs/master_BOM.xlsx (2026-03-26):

DO NOT BUY
Ref | Qty Ordered | Qty | Value | Product Link | Notes
C | 100 | 15 | 100n | https://www.digikey.com/en/products/detail/yageo/CC0603MPY5V9BB104/11490719
C | 10 | 1 | 10n | https://www.digikey.com/en/products/detail/kemet/C0603C103K5RACTU/411090
C | 10 | 3 | 470p | https://www.digikey.com/en/products/detail/kemet/C0603C471J5GACTU/2200803
C | 10 | 1 | 0.004u | NOT A STANDARD VALUE | 4.7nf
C | N/A | 1 | 0.01u |  | Covered by anther order unless there was a secret reason we left this one as a dup
C | 3 | 1 | 0.47u | https://www.digikey.com/en/products/detail/taiyo-yuden/UMK107B7474KA-TR/3194963
C | 10 | 2 | 4.7u | https://www.digikey.com/en/products/detail/murata-electronics/GRM188R61E475KE11D/3900465?_gl=1*1mvpjl7*_up*MQ..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
C | 3 | 1 | 0.3u | https://www.digikey.com/en/products/detail/tdk/CGA3E3X7R1H334K080AB/4931465 | I orderd 0.33????
C | 3 | 1 | 0.82u (These don’t exist???) | https://www.digikey.com/en/products/detail/yageo/CC0603KRX7R7BB824/16797392 | These only come in at 16V rated max, just max sure this works for yalls application
C | 10 | 2 | 0.001u I think? | https://www.digikey.com/en/products/detail/kemet/C0603C102K5RACTU/411081 | Marco is stupid and not sure if these are the two missing from power amp board
C | 10 | 1 | 68p | https://www.digikey.com/en/products/detail/johanson-technology-inc/QSCP251Q680J1GV001T/1561633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..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 | Joseph is greedy https://www.digikey.com/en/products/detail/walsin-technology-corporation/0603N680J500CT/9355039
C | 10 | 1 | 47n | https://www.digikey.com/en/products/detail/samsung-electro-mechanics/CL10B473KB8NNNC/3886721
C | 10 | 1 | 940p | https://www.digikey.com/en/products/detail/murata-electronics/GCM1885C2A911FA16D/16033413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..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 | Link is to 910 pf????
C | 10 | 1 | 0.0047u | https://www.digikey.com/en/products/detail/murata-electronics/GRM1885C1H472JA01D/4421616
C | 10 | 1 | 680p | https://www.digikey.com/en/products/detail/vishay-vitramon/VJ0603Y681KXACW1BC/8306532
C | 10 | 1 | 220p | https://www.digikey.com/en/products/detail/kemet/C0603C221K5RACTU/411073
C | N/A | 37 | 0.1u | https://www.digikey.com/en/products/detail/yageo/CC0603MPY5V9BB104/21285977?gclsrc=aw.ds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 | Covered by anther order unless there was a secret reason we left this one as a dup
C | 2 | 5 | 100u | https://www.digikey.com/en/products/detail/murata-electronics/GRM21BR60G107ME11K/13544362?gclsrc=aw.ds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 | Kyle and Joseph are actually D1 criminals dw Ill fix at some point
C | 12 | 6 | 10u | https://www.digikey.com/en/products/detail/murata-electronics/GRM188R61E106MA73J/5797706?gclsrc=aw.ds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
C | 50 | 33 | 1u | https://www.digikey.com/en/products/detail/taiyo-yuden/UMK107AB7105KA-T/3660085
C | 10 | 4 | 2.2u | https://www.digikey.com/en/products/detail/murata-electronics/GRM188R61E225KA12D/4905349
C | 12 | 6 | 22u | https://www.digikey.com/en/products/detail/kyocera-avx/0603YD226MAT2A/17866383
D | 5 | 2 | LED | https://www.digikey.com/en/products/detail/rohm-semiconductor/SML-D13M8WT86/5722632?gclsrc=aw.ds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
D |  | 3 | LED |  | Covered by anther order unless there was a secret reason we left this one as a dup
D | 14 | 7 | 1N4148W-13-F | https://www.digikey.com/en/products/detail/diodes-incorporated/1N4148W-13-F/1933928
D | 10 | 2 | 1N4148WT | https://www.digikey.com/en/products/detail/onsemi/1N4148WT/1954014
F | 2 | 1 | Fuse | https://www.digikey.com/en/products/detail/keystone-electronics/3568/2137306?gclsrc=aw.ds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
 | 25 | 11 | MINIFIT-2-VERT Male | https://www.digikey.com/en/products/detail/molex/0039012020/61315
J | 24 | 11 | MINIFIT-2-VERT Female | https://www.digikey.com/en/products/detail/molex/0039281023/61397
J | 6 | 3 | Conn_02x08_Counter_Clockwise | https://www.digikey.com/en/products/detail/sullins-connector-solutions/PPPC082LFBN-RC/810248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..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
J | 8 | 4 | MEGAFIT-2-VERT Male | https://www.digikey.com/en/products/detail/molex/0768290102/7604320
 | 8 | 4 | MEGAFIT-2-VERT Female | https://www.digikey.com/en/products/detail/molex/1716920102/4515271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
J | 2 | 1 | Conn_02x09_Counter_Clockwise | https://www.digikey.com/en/products/detail/molex/0430451812/531413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
J | N/A | 1 | TC2050 |  | ?????
J | N/A | 3 | Conn_02x08_Odd_Even |  | We can take these from the senior design shop
J | 2 | 1 | 39281023 | https://www.digikey.com/en/products/detail/molex/0039281023/61397?s=N4IgTCBcDaIMwE4wA4CMAGMcQF0C%2BQA
J | 4 | 2 | 2068320801 | https://www.digikey.com/en/products/detail/molex/2068320801/10209714?s=N4IgTCBcDa4AwDYAcBmMclwIwgLoF8g
 | 4 | 2 | 2064610800 | https://www.digikey.com/en/products/detail/molex/2064610800/10209702
J | N/A | 1 | USB_Breakout
J | 3 | 1 | Molex_Mega-Fit_76829-0004_2x02_P5.70mm_Vertical | https://www.mouser.com/ProductDetail/Molex/76829-0004?qs=KpdAywxU0120juwtNw8Xjw%3D%3D | also got mate: https://www.mouser.com/ProductDetail/Molex/170001-0104?qs=MxnWX8BLHKfaXqdKbFiMEg%3D%3D
J | 4 | 2 | Conn_01x02 |  | Molex_Mini-Fit_Jr_5566-02A_2x01_P4.20mm_Vertical
J | 2 | 1 | Molex_Mini-Fit_Jr_5566-04A_2x02_P4.20mm_Vertical
J | 2 | 1 | Microfit 2 position | https://www.google.com/aclk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
J | 3 | 1 | pin header 1x02 | https://www.digikey.com/en/products/detail/amphenol-icc-fci-/10129378-902002BLF/7915925?gclsrc=aw.ds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
J | 2 | 1 | NMJ6HFD2 | https://www.google.com/aclk?ae=2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
 | 10 | 5 | Conn_01x03 | https://www.digikey.com/en/products/detail/molex/0436450310/7062847?gclsrc=aw.ds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
J | 10 | 5 | Conn_01x03 | https://www.google.com/aclk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
POT | N/A | 3 | R_Potentiometer_US |  | We have these already
PS | 1 | 1 | TMV_1205D | https://www.digikey.com/en/products/detail/traco-power/TMV-1205D/9383529
PS | 2 | 2 | R-78K5.0-0.5 | https://www.digikey.com/en/products/detail/recom-power/R-78K5-0-0-5/18093025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
PS | 1 | 1 | IRM-60-12 | https://www.digikey.com/en/products/detail/mean-well-usa-inc/IRM-60-12/7704688
Q | 10 | 5 | BC549 | https://www.digikey.com/en/products/detail/diotec-semiconductor/BC549C/22192148
Q | N/A | 2 | 2N3904 |  | We will use the ones at gt
Q | N/A | 4 | Q_NJFET_DSG
Q | 2 | 1 | BC559 | https://www.digikey.com/en/products/detail/diotec-semiconductor/BC559C/22190267
Q | N/A | 2 | MJ15004 |  | we will steal from robinson
Q | N/A | 2 | MJ15003 |  | we will steal from robinson
Q | N/A | 1 | Q_NJFET_DSG
R | 10 | 3 | 27k | https://www.digikey.com/en/products/detail/yageo/RC0603FR-1327KL/14287589?gclsrc=aw.ds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
R | 10 | 4 | 440 | https://www.digikey.com/en/products/detail/yageo/RC0603FR-10430RL/14287773?gclsrc=aw.ds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
R | 10 | 1 | 1.2k | https://www.google.com/aclk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
R | 10 | 3 | 4.7k | https://www.google.com/aclk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
R | 10 | 2 | 240 | https://www.google.com/aclk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
R | 25 | 9 | 150 | https://www.google.com/aclk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
R | 50 | 17 | 10k | https://www.google.com/aclk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
R | 10 | 3 | 33k | https://www.digikey.com/en/products/detail/panasonic-electronic-components/ERA-3AEB333V/1465890
R | 10 | 4 | 470k | https://www.digikey.com/en/products/detail/yageo/RC0603FR-07470KL/727257
R | 10 | 2 | 8.2k | https://www.digikey.com/en/products/detail/panasonic-electronic-components/ERJ-3EKF8201V/1746448
R | 10 | 4 | 12k | https://www.digikey.com/en/products/detail/panasonic-electronic-components/ERA-3AEB123V/1465880
R | 10 | 1 | 560 | https://www.digikey.com/en/products/detail/yageo/RC0603FR-07560RL/727304
R | 20 | 4 | 500k |  | Chud Marco will get 499 k ohm resistors
R | 10 | 2 | 4.7k
R | 10 | 4 | 0 | https://www.digikey.com/en/products/detail/yageo/RC0603JR-070RL/726675
R | 10 | 1 | 130k | https://www.digikey.com/en/products/detail/stackpole-electronics-inc/RMCF0603FT130K/1761272
R | 10 | 1 | 18k | https://www.digikey.com/en/products/detail/yageo/RC0603JR-0718KL/726725
R | 10 | 1 | 40k | https://www.digikey.com/en/products/detail/yageo/RT0603BRD0740KL/7708329
R | 10 | 1 | 36k | https://www.digikey.com/en/products/detail/stackpole-electronics-inc/RMCF0603FT36K0/1713967
R | 10 | 2 | 9k | https://www.digikey.com/en/products/detail/yageo/RT0603FRE078K98L/17020100 | I got 1% 8.98kOhms
R | 10 | 4 | 1M | https://www.digikey.com/en/products/detail/yageo/RC0603FR-071ML/726844
R | 10 | 2 | 2k | https://www.digikey.com/en/products/detail/yageo/RC0603FR-072KL/727009
R | 10 | 1 | 3k | https://www.digikey.com/en/products/detail/panasonic-electronic-components/ERA-3AEB302V/1465865
R | 10 | 1 | 150k | https://www.digikey.com/en/products/detail/panasonic-electronic-components/ERA-3AEB154V/1465906
R | 10 | 1 | 15k | https://www.digikey.com/en/products/detail/panasonic-electronic-components/ERA-3AEB153V/1465882
R | 25 | 12 | 1k | https://www.digikey.com/en/products/detail/stackpole-electronics-inc/RMCF0603FT1K00/1761077
R | 10 | 1 | 2.4k | https://www.digikey.com/en/products/detail/vishay-dale/CRCW06032K40FKEA/1174709
R | 10 | 5 | 6.2k | https://www.digikey.com/en/products/detail/yageo/RC0603FR-076K2L/727319
R | 25 | 8 | 510 | https://www.digikey.com/en/products/detail/yageo/RC0603FR-07510RL/727285
R | 10 | 3 | 20k | https://www.digikey.com/en/products/detail/panasonic-electronic-components/ERA-3AEB203V/1465885
R | 8 | 4 | 4.7 | https://www.digikey.com/en/products/detail/susumu/CPA2512Q4R70FS-T10/1935788
R | 10 | 1 | 499k | https://www.digikey.com/en/products/detail/yageo/AC0603FR-07499KL/12707691?gclsrc=aw.ds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
R | 25 | 7 | 100 | https://www.digikey.com/en/products/detail/yageo/RC0603FR-13100RL/12756438?gclsrc=aw.ds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
R | 10 | 1 | 50k | https://www.digikey.com/en/products/detail/yageo/RT0603BRD0750KL/7708337
R | 10 | 4 | 7.5k | https://www.digikey.com/en/products/detail/stackpole-electronics-inc/RMEF0603FT7K50/16840016?gclsrc=aw.ds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
R | 10 | 3 | 2.7k | https://www.digikey.com/en/products/detail/yageo/RC0603FR-072K7P/22199799?gclsrc=aw.ds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
R | 25 | 9 | 100k | https://www.digikey.com/en/products/detail/yageo/RC0603FR-13100KL/12756433?gclsrc=aw.ds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
R | 4 | 2 | 100 | 1 W Resistor | Is this still 0603?? https://www.digikey.com/en/products/detail/vishay-dale/RCP0603W100RGEB/5481867
SW | N/A | 1 | SW_SPDT |  | We have this already
SW | 3 | 1 | SW_Omron_B3FS | https://www.digikey.com/en/products/detail/omron-electronics-inc-emc-div/B3FS-1000/3487234?gclsrc=aw.ds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
SW | N/A | 1 | SW_Push_Open |  | We have this already
SW | 3 | 1 | SW_SPST | https://www.digikey.com/en/products/detail/omron-electronics-inc-emc-div/B3U-1000P/1534338
U | 10 | 9 | TS12A12511DCNR | https://www.digikey.com/en/products/detail/texas-instruments/TS12A12511DCNR/2328661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
U | 2 | 1 | R-78C3.3-1.0 | https://www.digikey.com/en/products/detail/recom-power/R-78K3.3-1.0/18093033?gclsrc=aw.ds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
U | 1 | 1 | TMA-1205D | https://www.digikey.com/en/products/detail/traco-power/TMA-1205D/9383352 | We alreadty have spare from digicorder
U | 10 | 3 | 74LVC1G17 | https://www.digikey.com/en/products/detail/texas-instruments/SN74LVC1G17DBVRG4/4833886?gclsrc=aw.ds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
U | 1 | 1 | STM32G474RETx | https://www.digikey.com/en/products/detail/stmicroelectronics/STM32G474RET6/10326780 | If we need more we take from shop no?
U | 10 | 4 | TPL0501-100DCNR | https://www.digikey.com/en/products/detail/texas-instruments/TPL0501-100DCNR/2755770
U | 4 | 2 | ADP7118AUJZ-4.5-R7 | https://www.digikey.com/en/products/detail/analog-devices-inc/ADP7118AUJZ-4-5-R7/6599734
U | 2 | 1 | LM2940IMP-9.0/NOPB | https://www.digikey.com/en/products/detail/texas-instruments/LM2940IMP-9-0-NOPB/363894
U | N/A | 1 | Daisy_Seed
U | N/A | 1 | Daisy_Seed_Recording
U | 2 | 1 | AD5160 | https://www.digikey.com/en/products/detail/analog-devices-inc/AD5160BRJZ10-RL7/652799
U | 2 | 1 | AD8400ARZ1 | https://www.digikey.com/en/products/detail/analog-devices-inc/AD8400ARZ1/751162
U | 2 | 1 | AD5290 | https://www.digikey.com/en/products/detail/analog-devices-inc/AD5290YRMZ50-R7/1217962
U | 4 | 2 | ADA4522-2ARMZ-R7 | https://www.digikey.com/en/products/detail/analog-devices-inc/ADA4522-2ARMZ-R7/5268023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
U | 1 | 1 | AC025-D24 | https://www.digikey.com/en/products/detail/adam-tech/AC025-D24/22469417 | gulp
U | 41 | 20 | TL071HIDBVR | https://www.digikey.com/en/products/detail/texas-instruments/TL071HIDBVR/14835784
U | 2 | 1 | TMA-1215D | https://www.digikey.com/en/products/detail/traco-power/TMA-1215D/9383617
 |  |  |  | https://www.digikey.com/en/products/detail/molex/0039012020/61315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
 |  |  |  | https://www.google.com/aclk?ae=2&co=1&ase=2&q=&nis=4&adurl=

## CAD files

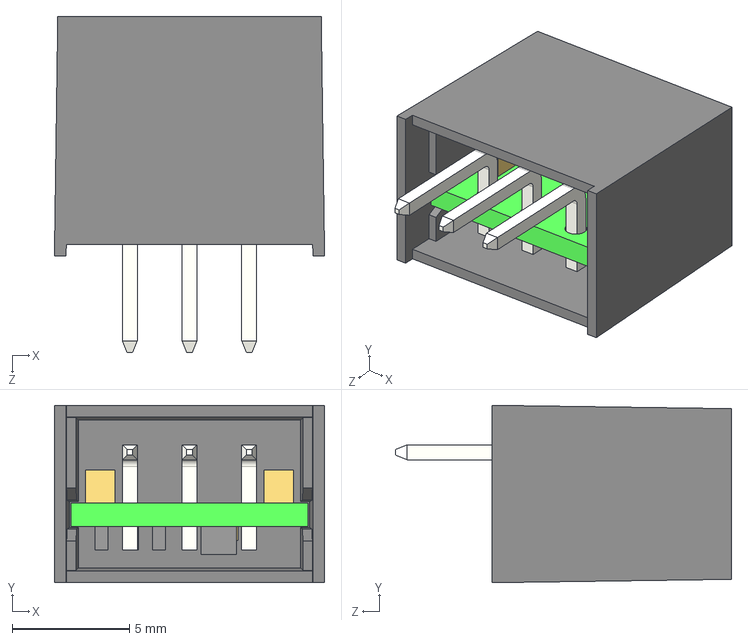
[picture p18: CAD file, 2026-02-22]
Digital and Recording Board/symbols/R-78K5.0-0.5/R-78K5.0-0.5.step
11.5 x 7.55 x 14.3 mm

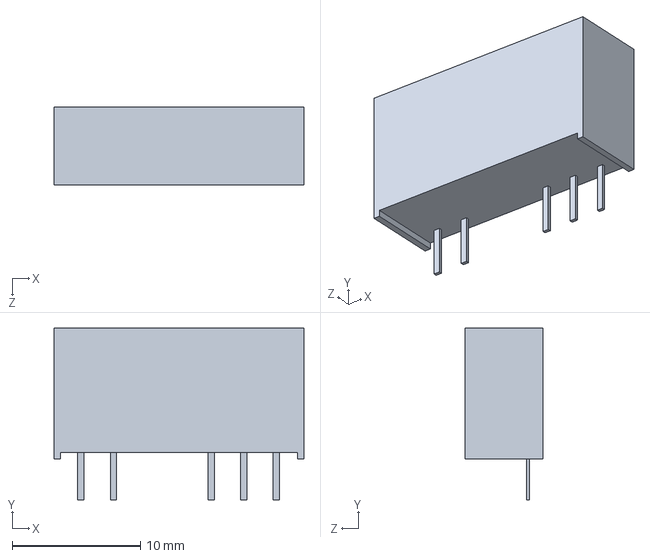
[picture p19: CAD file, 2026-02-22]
Digital and Recording Board/symbols/TMV_1205D/TMV_1205D.step
19.5 x 13.4 x 6.10 mm

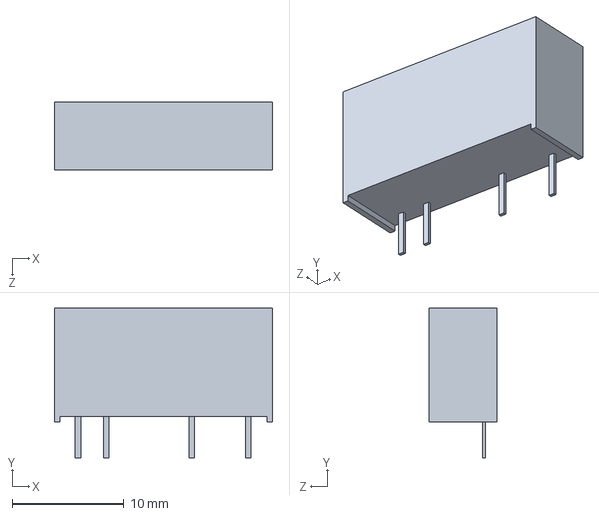
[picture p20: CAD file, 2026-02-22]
Digital and Recording Board/symbols/TMV_1205S/TMV_1205S.step
19.5 x 13.4 x 6.10 mm

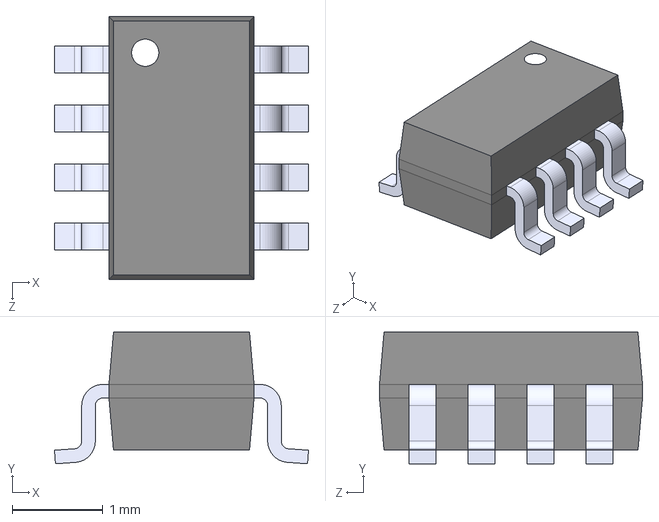
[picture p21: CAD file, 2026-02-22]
Digital and Recording Board/symbols/TS12A12511DCNR/TS12A12511DCNR.step
2.80 x 1.45 x 2.90 mm

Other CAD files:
Analog Controller/Analog Controller/New Symbols/284697-E/Allegro/284697e.psm
Analog Controller/Analog Controller/New Symbols/284697-E/DEHDL/284697_e/chips/chips.prt

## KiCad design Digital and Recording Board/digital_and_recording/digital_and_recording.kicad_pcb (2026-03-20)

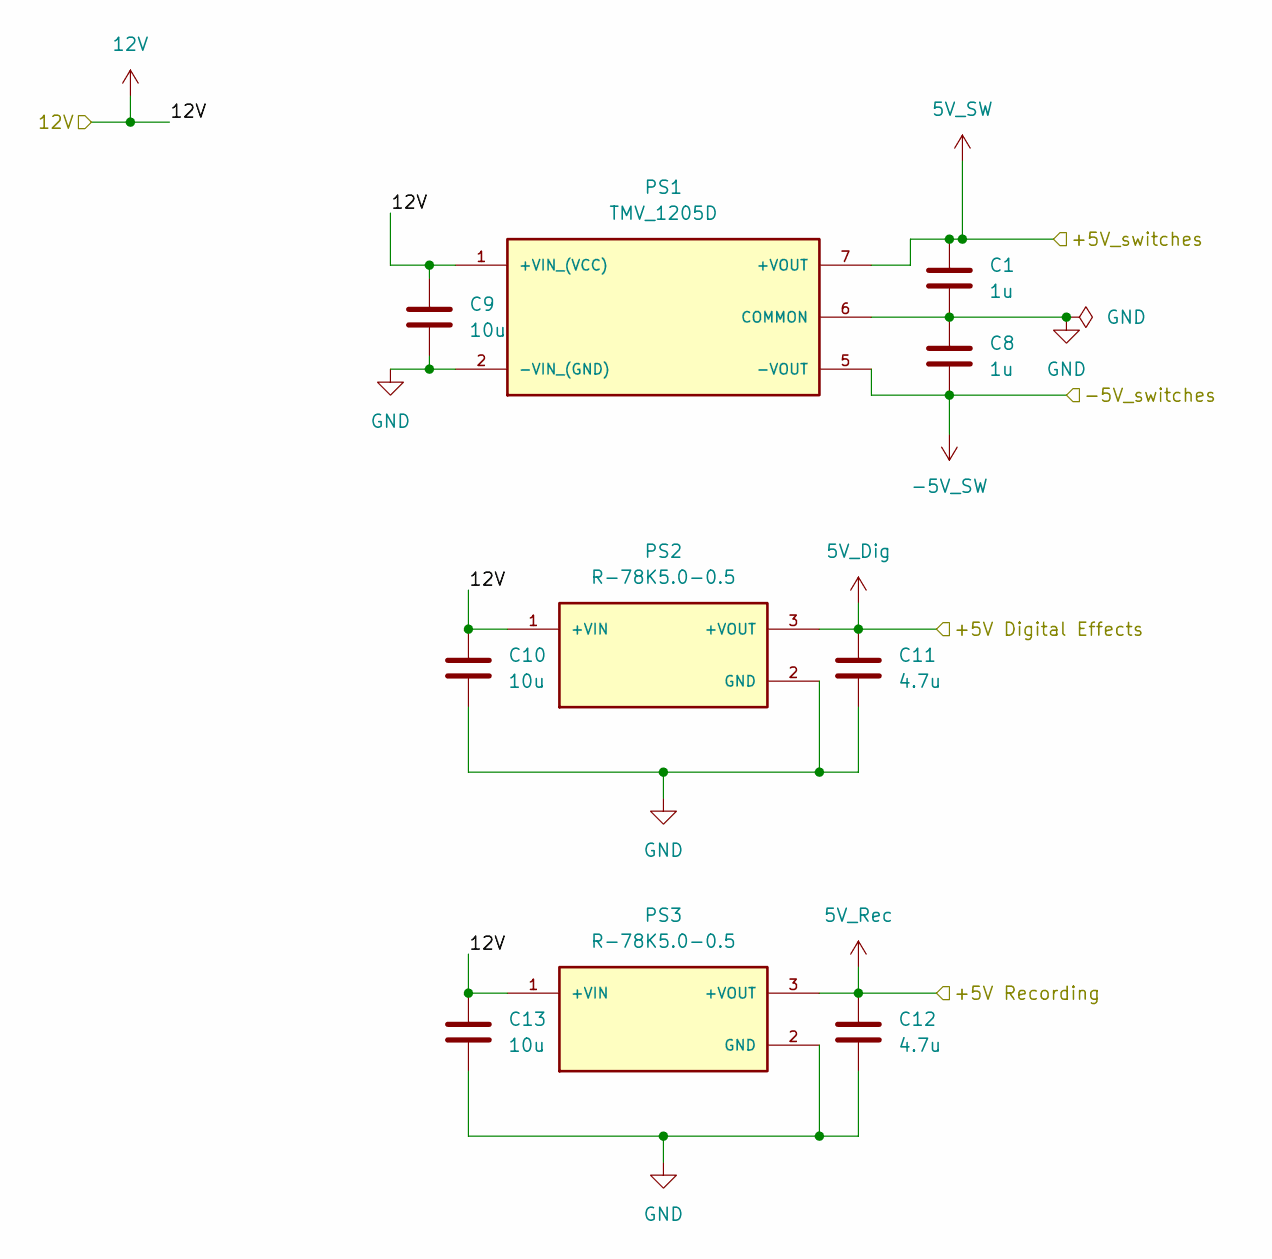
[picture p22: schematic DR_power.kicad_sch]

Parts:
C1, C8: 1u; C_0603_1608Metric
C9, C10, C13: 10u; C_0603_1608Metric
C11, C12: 4.7u; C_0603_1608Metric
PS1: TMV_1205D; CONV_TMV_1205D; PARTREV March 26, 2020; DigiKey_Part_Number 1951-2505-ND
PS2, PS3: R-78K5.0-0.5; CONV_R-78K5.0-0.5; PARTREV 0/2023; DigiKey_Part_Number 945-R-78K5.0-0.5-ND

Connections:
5V_Dig: C11.1, PS2.3 (+VOUT); also elsewhere on the board
5V_Rec: C12.1, PS3.3 (+VOUT); also elsewhere on the board
5V_SW: C1.1, PS1.7 (+VOUT); also elsewhere on the board
12V: C9.1, C10.1, C13.1, PS1.1 (+VIN_(VCC)), PS2.1 (+VIN), PS3.1 (+VIN); also elsewhere on the board
-5V_SW: C8.2, PS1.5 (-VOUT); also elsewhere on the board
GND: C1.2, C8.1, C9.2, C10.2, C11.2, C12.2, C13.2, PS1.2 (-VIN_(GND)), PS1.6 (COMMON), PS2.2 (GND), PS3.2 (GND); also elsewhere on the board

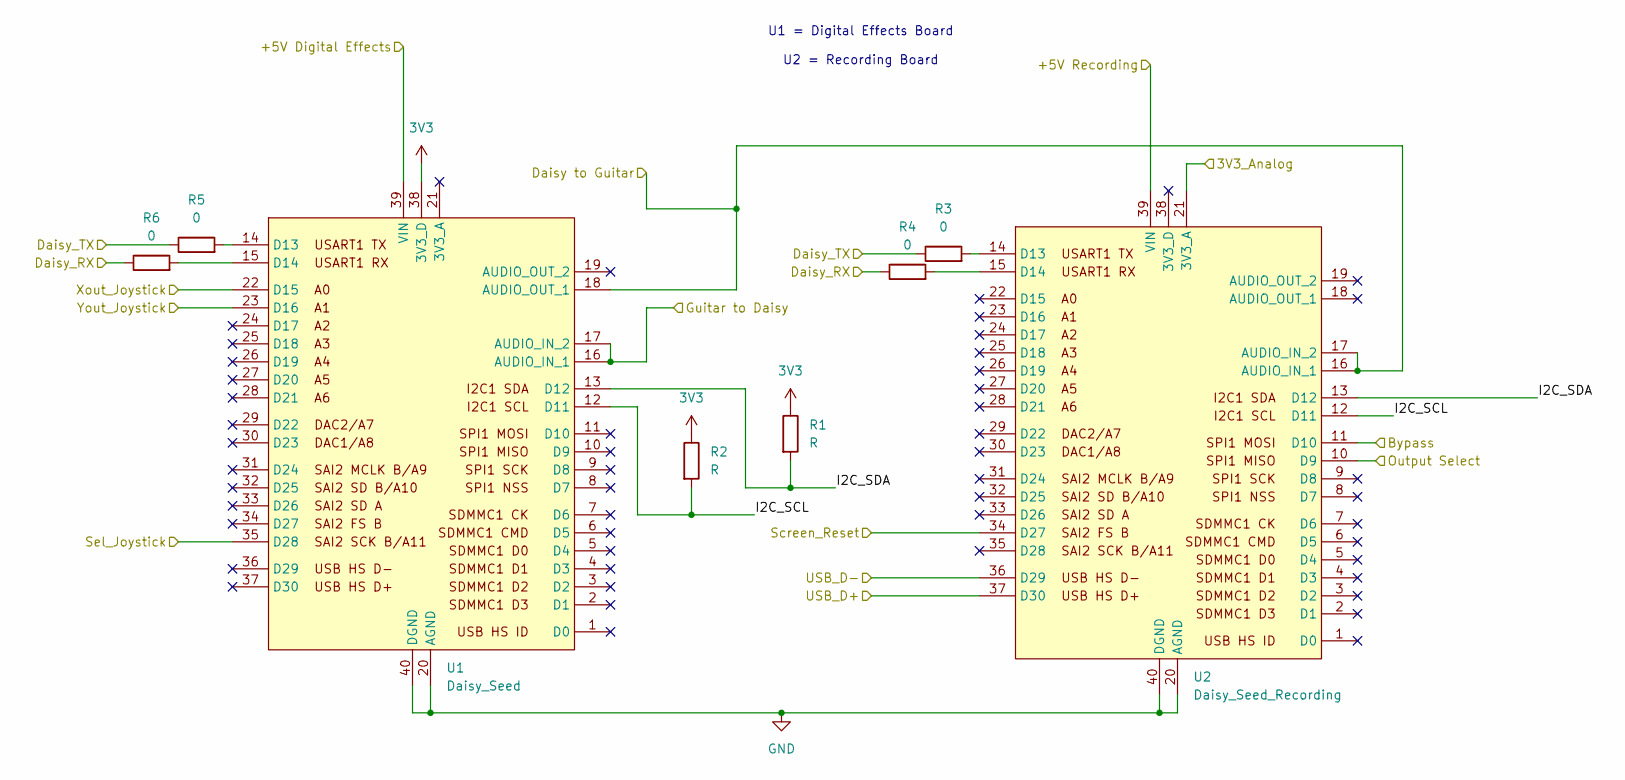
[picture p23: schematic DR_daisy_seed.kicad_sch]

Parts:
R1, R2: R; R_0603_1608Metric
R3, R4, R5, R6: 0; R_0603_1608Metric
U1: Daisy_Seed; DAISY_SEED
U2: Daisy_Seed_Recording; DAISY_SEED

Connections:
3V3: R1.1, R2.1, U1.38 (3V3_D)
5V_Dig: U1.39 (VIN); also elsewhere on the board
5V_Rec: U2.39 (VIN); also elsewhere on the board
/Connectors/3V3_Analog: U2.21 (3V3_A); also elsewhere on the board
/Connectors/Bypass: U2.11 (D10); also elsewhere on the board
/Connectors/Daisy to Guitar: U1.18 (AUDIO_OUT_1), U2.16 (AUDIO_IN_1), U2.17 (AUDIO_IN_2); also elsewhere on the board
/Connectors/Daisy_RX: R4.1, R6.1; also elsewhere on the board
/Connectors/Daisy_TX: R3.1, R5.1; also elsewhere on the board
/Connectors/Guitar to Daisy: U1.16 (AUDIO_IN_1), U1.17 (AUDIO_IN_2); also elsewhere on the board
/Connectors/Output Select: U2.10 (D9); also elsewhere on the board
/Connectors/Screen_Reset: U2.34 (D27); also elsewhere on the board
/Connectors/Sel_Joystick: U1.35 (D28); also elsewhere on the board
/Connectors/USB_D+: U2.37 (D30); also elsewhere on the board
/Connectors/USB_D-: U2.36 (D29); also elsewhere on the board
/Connectors/Xout_Joystick: U1.22 (D15); also elsewhere on the board
/Connectors/Yout_Joystick: U1.23 (D16); also elsewhere on the board
/Daisy Seed/I2C_SCL: R2.2, U1.12 (D11), U2.12 (D11)
/Daisy Seed/I2C_SDA: R1.2, U1.13 (D12), U2.13 (D12)
GND: U1.20 (AGND), U1.40 (DGND), U2.20 (AGND), U2.40 (DGND); also elsewhere on the board
unnamed: R5.2, U1.14 (D13)
unnamed: R6.2, U1.15 (D14)
unnamed: R3.2, U2.14 (D13)
unnamed: R4.2, U2.15 (D14)

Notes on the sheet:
U1 = Digital Effects Board U2 = Recording Board

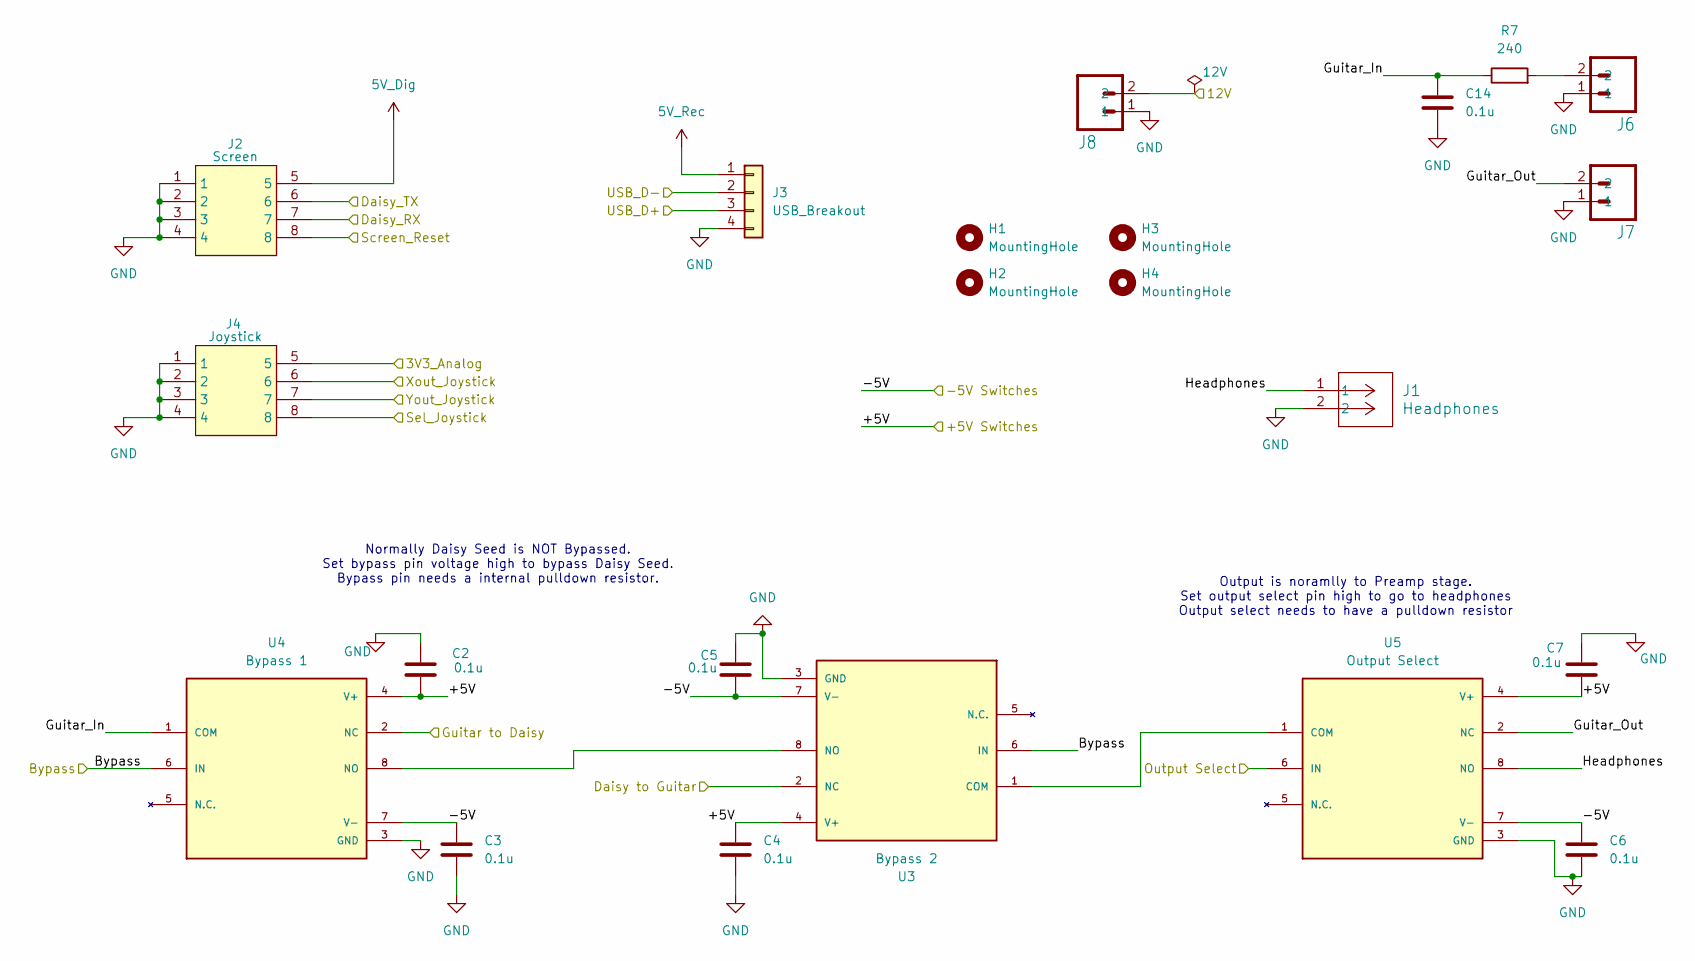
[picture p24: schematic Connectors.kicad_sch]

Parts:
C2, C3, C4, C5, C6, C7, C14: 0.1u; C_0603_1608Metric
H1, H2, H3, H4: MountingHole; MountingHole_2.7mm_M2.5
J1: Headphones; CONN_SD-5566-002_02_MOL
J2: Screen; MOLEX_2068320801
J3: USB_Breakout; PinHeader_1x04_P2.54mm_Vertical
J4: Joystick; MOLEX_2068320801
J6, J7: MINIFIT-2-VERT; Molex_Mini-Fit_Jr_5566-02A_2x01_P4.20mm_Vertical
J8: MINIFIT-2-VERT; Molex_Mega-Fit_76829-0102_2x01_P5.70mm_Vertical
R7: 240; R_0603_1608Metric
U3: Bypass 2; SOT65P280X145-8N; PARTREV E; DigiKey_Part_Number 296-27523-1-ND
U4: Bypass 1; SOT65P280X145-8N; PARTREV E; DigiKey_Part_Number 296-27523-1-ND
U5: Output Select; SOT65P280X145-8N; PARTREV E; DigiKey_Part_Number 296-27523-1-ND

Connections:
5V_Dig: J2.5; also elsewhere on the board
5V_Rec: J3.1; also elsewhere on the board
5V_SW: C2.2, C4.1, C7.2, U3.4 (V+), U4.4 (V+), U5.4 (V+); also elsewhere on the board
12V: J8.2; also elsewhere on the board
-5V_SW: C3.1, C5.2, C6.1, U3.7 (V-), U4.7 (V-), U5.7 (V-); also elsewhere on the board
/Connectors/3V3_Analog: J4.5; also elsewhere on the board
/Connectors/Bypass: U3.6 (IN), U4.6 (IN); also elsewhere on the board
/Connectors/Daisy to Guitar: U3.2 (NC); also elsewhere on the board
/Connectors/Daisy_RX: J2.7; also elsewhere on the board
/Connectors/Daisy_TX: J2.6; also elsewhere on the board
/Connectors/Guitar to Daisy: U4.2 (NC); also elsewhere on the board
/Connectors/Guitar_In: C14.1, R7.1, U4.1 (COM)
/Connectors/Guitar_Out: J7.2, U5.2 (NC)
/Connectors/Headphones: J1.1, U5.8 (NO)
/Connectors/Output Select: U5.6 (IN); also elsewhere on the board
/Connectors/Screen_Reset: J2.8; also elsewhere on the board
/Connectors/Sel_Joystick: J4.8; also elsewhere on the board
/Connectors/USB_D+: J3.3; also elsewhere on the board
/Connectors/USB_D-: J3.2; also elsewhere on the board
/Connectors/Xout_Joystick: J4.6; also elsewhere on the board
/Connectors/Yout_Joystick: J4.7; also elsewhere on the board
GND: C2.1, C3.2, C4.2, C5.1, C6.2, C7.1, C14.2, J1.2, J2.1, J2.2, J2.3, J2.4, J3.4, J4.1, J4.2, J4.3, J4.4, J6.1, J7.1, J8.1, U3.3 (GND), U4.3 (GND), U5.3 (GND); also elsewhere on the board
unnamed: J6.2, R7.2
unnamed: U3.1 (COM), U5.1 (COM)
unnamed: U3.8 (NO), U4.8 (NO)

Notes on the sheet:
Normally Daisy Seed is NOT Bypassed. Set bypass pin voltage high to bypass Daisy Seed. Bypass pin needs a internal pulldown resistor.
Output is noramlly to Preamp stage. Set output select pin high to go to headphones Output select needs to have a pulldown resistor

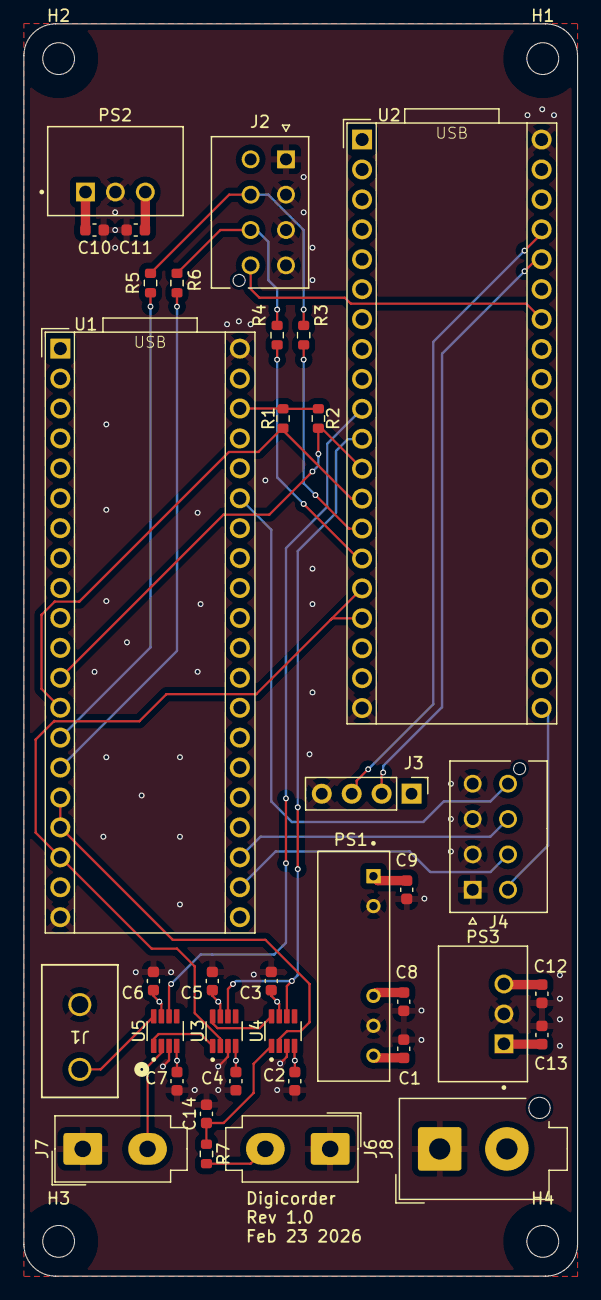
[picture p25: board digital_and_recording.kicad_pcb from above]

Board: 4 copper layers, 47.0 x 106.3 mm, 40 parts (0 on the bottom side), 32 nets.

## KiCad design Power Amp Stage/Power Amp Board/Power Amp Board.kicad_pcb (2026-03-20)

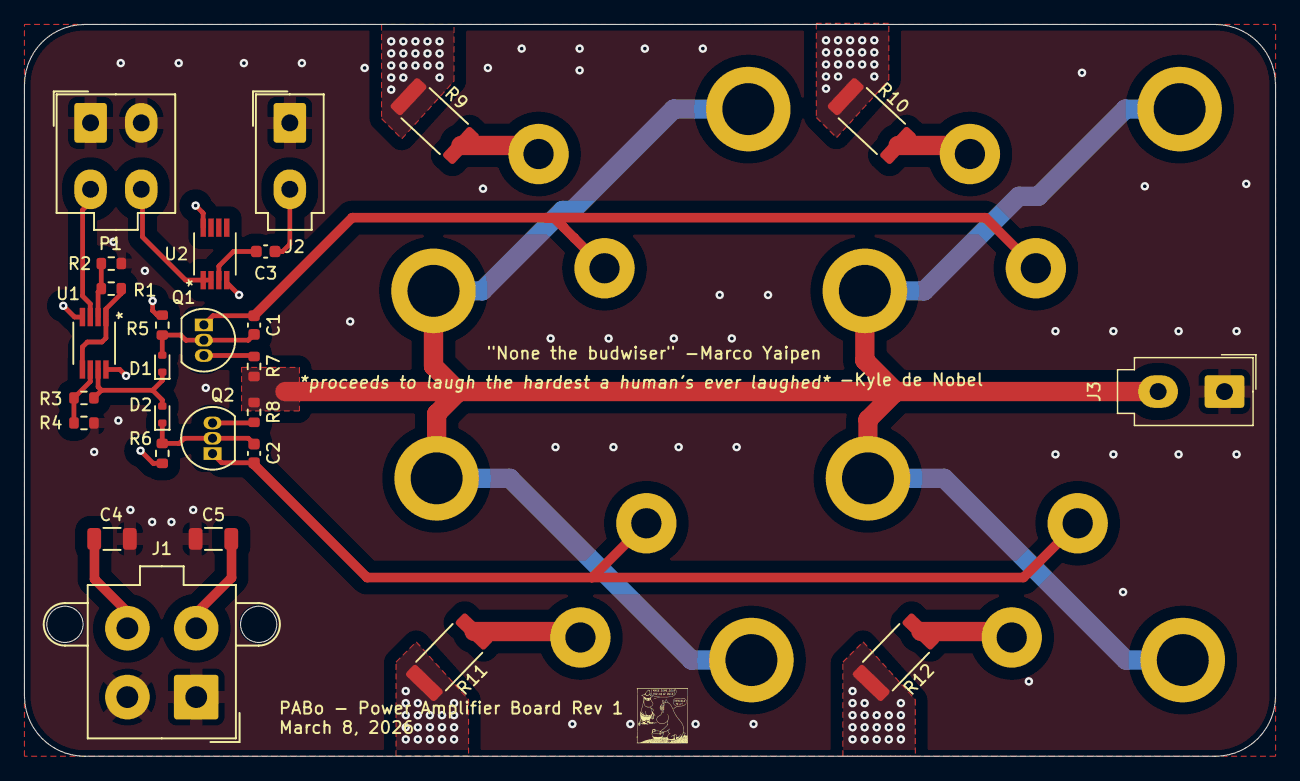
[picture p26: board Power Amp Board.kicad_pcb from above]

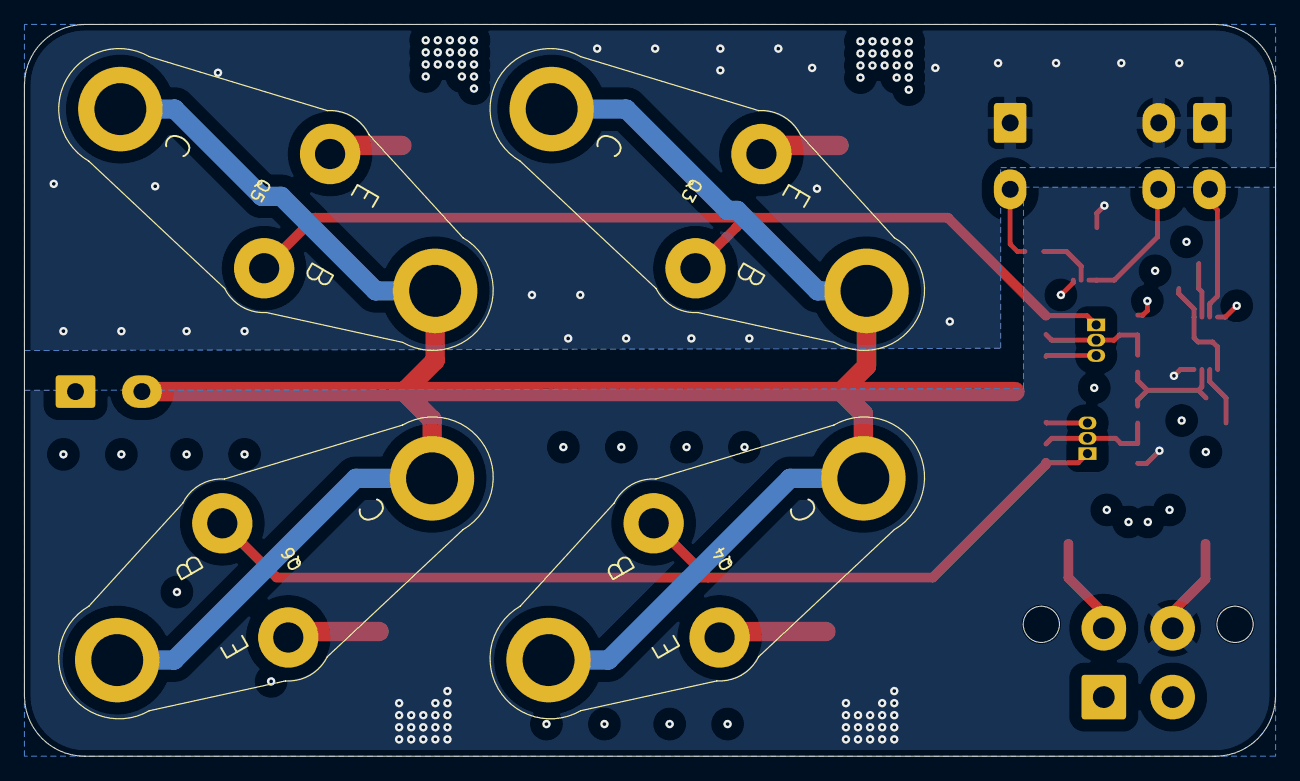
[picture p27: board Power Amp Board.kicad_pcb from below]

Board: 4 copper layers, 103.6 x 60.6 mm, 31 parts (4 on the bottom side), 22 nets.

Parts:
C1, C2: C; C_0603_1608Metric
C3: 0.1u; C_0603_1608Metric
C4, C5: 100u; C_1206_3216Metric
D1, D2: 1N4148WT; D_SOD-523
J1: Molex_Mega-Fit_76829-0004_2x02_P5.70mm_Vertical
J2, J3: Conn_01x02; Molex_Mini-Fit_Jr_5566-02A_2x01_P4.20mm_Vertical
P1: Molex_Mini-Fit_Jr_5566-04A_2x02_P4.20mm_Vertical
Q1: BC549; TO-92_Inline
Q2: BC559; TO-92_Inline
Q3, Q5: MJ15004; MJ15000
Q4, Q6: MJ15003; MJ15000
R1, R3: 100k; R_0603_1608Metric
R2, R4, R5, R6: 10k; R_0603_1608Metric
R7, R8: 100; R_0603_1608Metric
R9, R10, R11, R12: 4.7; R_2512_6332Metric
U1, U2: ADA4522-2ARMZ-R7; RM-8_ADI

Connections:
24V: C5.1, J1.3, R5.1, R9.1, R10.1, U1.4 (V-), U2.4 (V-)
-24V: C4.1, J1.4, R6.2, R11.2, R12.2, U1.8 (V+), U2.8 (V+)
/audio_in+: C3.1, J2.2
/audio_out+: J3.2, Q3.3 (C), Q4.3 (C), Q5.3 (C), Q6.3 (C), R7.2, R8.1
/buffer: P1.4 (H), U2.1 (OUTA), U2.2 (INA-)
/out1: R1.1, U1.1 (OUTA), U1.5 (INB+)
/out2: D1.1 (K), D2.2 (A), R3.1, U1.7 (OUTB)
/post_pot: P1.3 (W), U1.3 (INA+)
GND: C4.2, C5.2, J1.1, J1.2, J2.1, J3.1, P1.1 (GND), P1.2 (L), R2.1, R4.1
unnamed: C1.2, D1.2 (A), Q1.2 (B), R5.2
unnamed: C2.1, D2.1 (K), Q2.2 (B), R6.1
unnamed: C1.1, Q1.1 (C), Q3.2 (B), Q5.2 (B)
unnamed: Q1.3 (E), R7.1
unnamed: C2.2, Q2.1 (C), Q4.2 (B), Q6.2 (B)
unnamed: Q2.3 (E), R8.2
unnamed: Q3.1 (E), R9.2
unnamed: Q4.1 (E), R11.1
unnamed: Q5.1 (E), R10.2
unnamed: Q6.1 (E), R12.1
unnamed: R1.2, R2.2, U1.2 (INA-)
unnamed: R3.2, R4.2, U1.6 (INB-)
unnamed: C3.2, U2.3 (INA+)

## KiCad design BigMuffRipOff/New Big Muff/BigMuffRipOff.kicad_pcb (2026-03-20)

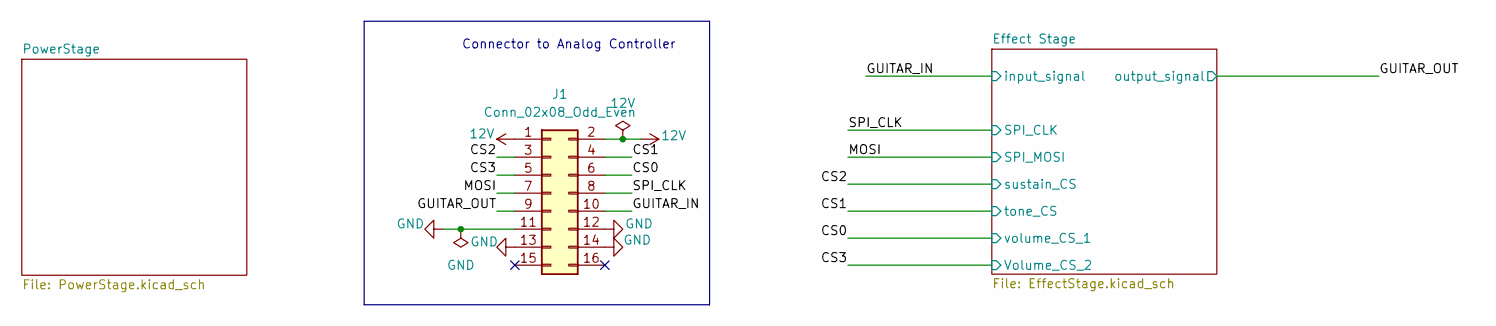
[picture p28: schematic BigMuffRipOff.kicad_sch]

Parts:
J1: Conn_02x08_Odd_Even; PinHeader_2x08_P2.54mm_Horizontal

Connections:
12V: J1.1, J1.2; also elsewhere on the board
/CS0: J1.6; also elsewhere on the board
/CS1: J1.4; also elsewhere on the board
/CS2: J1.3; also elsewhere on the board
/CS3: J1.5; also elsewhere on the board
/GUITAR_IN: J1.10; also elsewhere on the board
/GUITAR_OUT: J1.9; also elsewhere on the board
/MOSI: J1.7; also elsewhere on the board
/SPI_CLK: J1.8; also elsewhere on the board
GND: J1.11, J1.12, J1.13, J1.14; also elsewhere on the board

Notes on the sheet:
Connector to Analog Controller

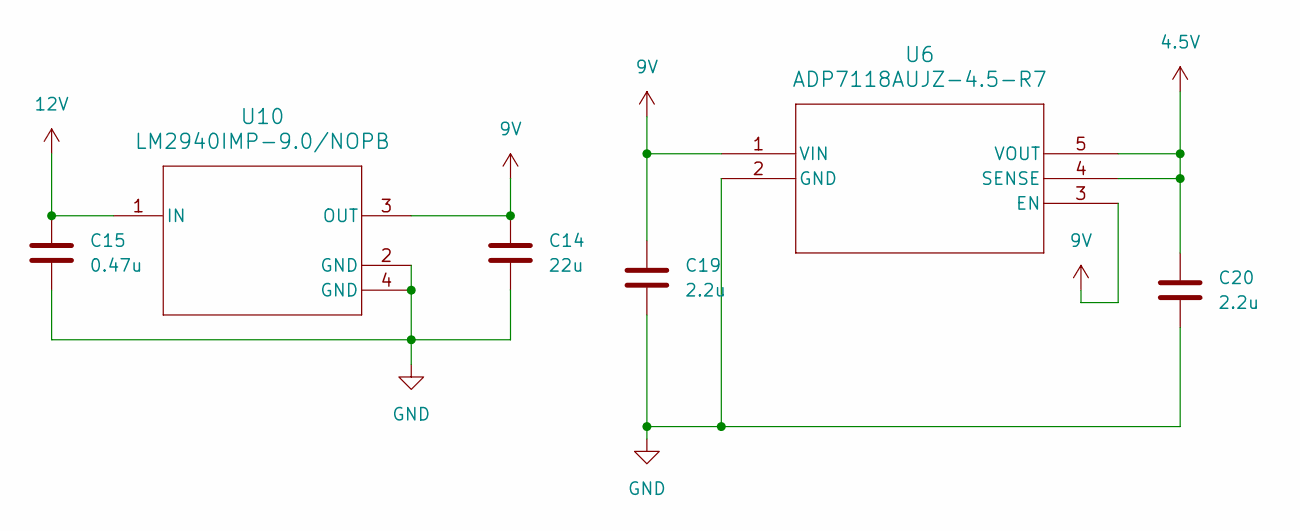
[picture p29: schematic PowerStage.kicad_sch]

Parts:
C14: 22u; C_0603_1608Metric
C15: 0.47u; C_0603_1608Metric
C19, C20: 2.2u; C_0603_1608Metric
U6: ADP7118AUJZ-4.5-R7; UJ-5_ADI
U10: LM2940IMP-9.0/NOPB; DCY0004A_N

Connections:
4.5V: C20.1, U6.4 (SENSE), U6.5 (VOUT); also elsewhere on the board
9V: C14.1, C19.1, U6.1 (VIN), U6.3 (EN), U10.3 (OUT); also elsewhere on the board
12V: C15.1, U10.1 (IN); also elsewhere on the board
GND: C14.2, C15.2, C19.2, C20.2, U6.2 (GND), U10.2 (GND), U10.4 (GND); also elsewhere on the board

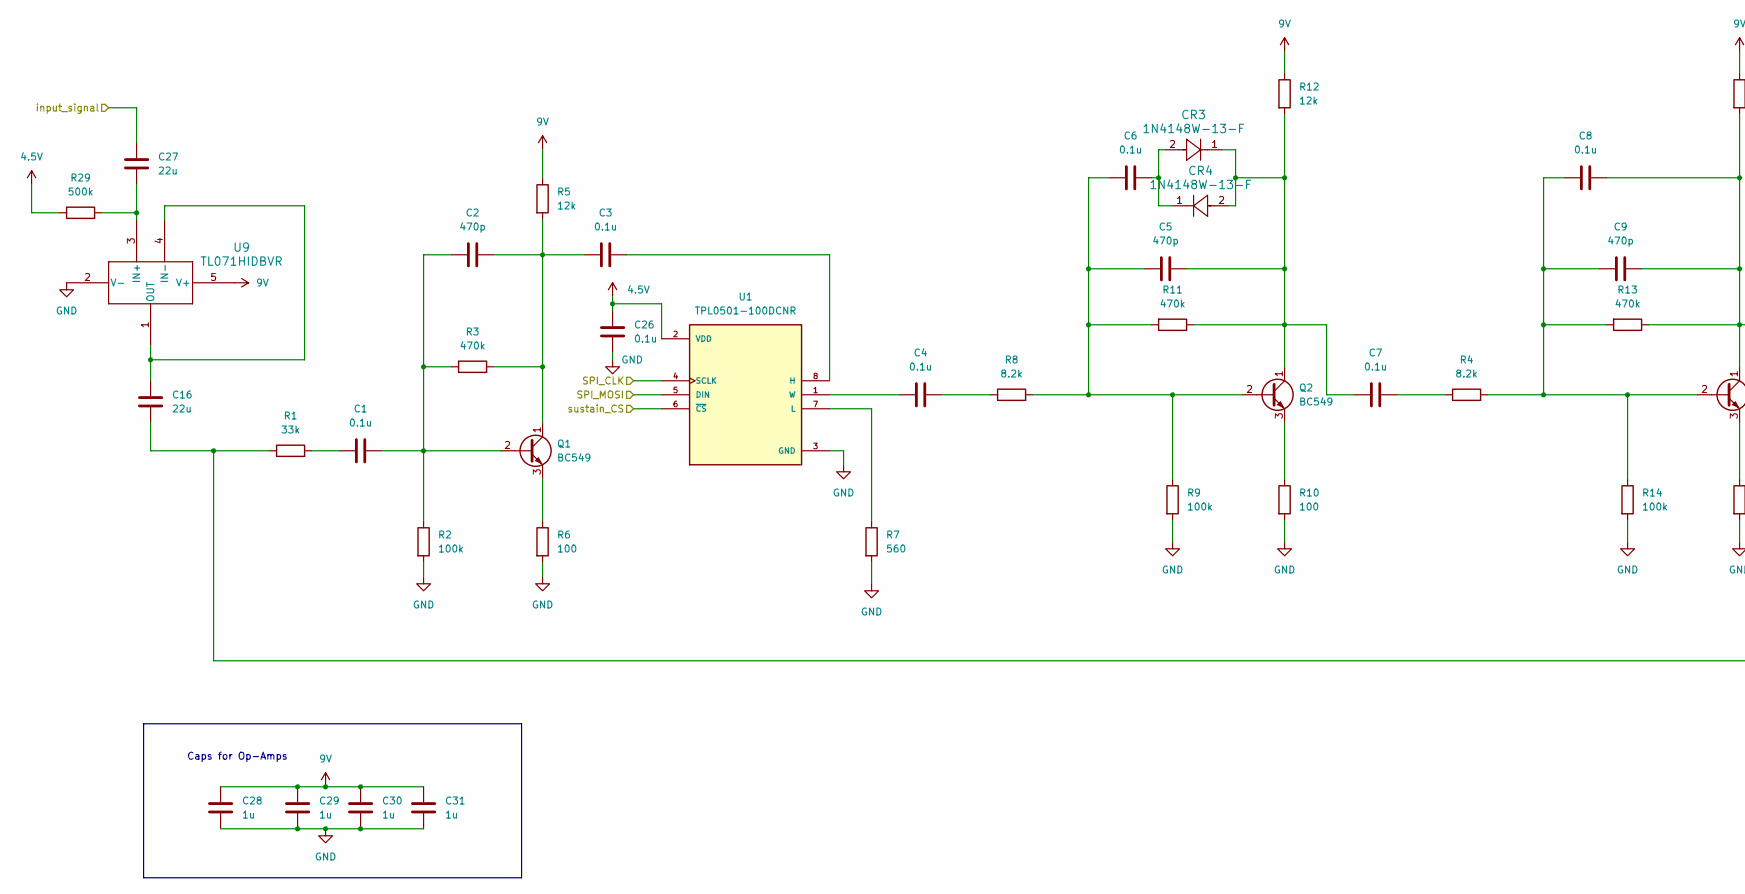
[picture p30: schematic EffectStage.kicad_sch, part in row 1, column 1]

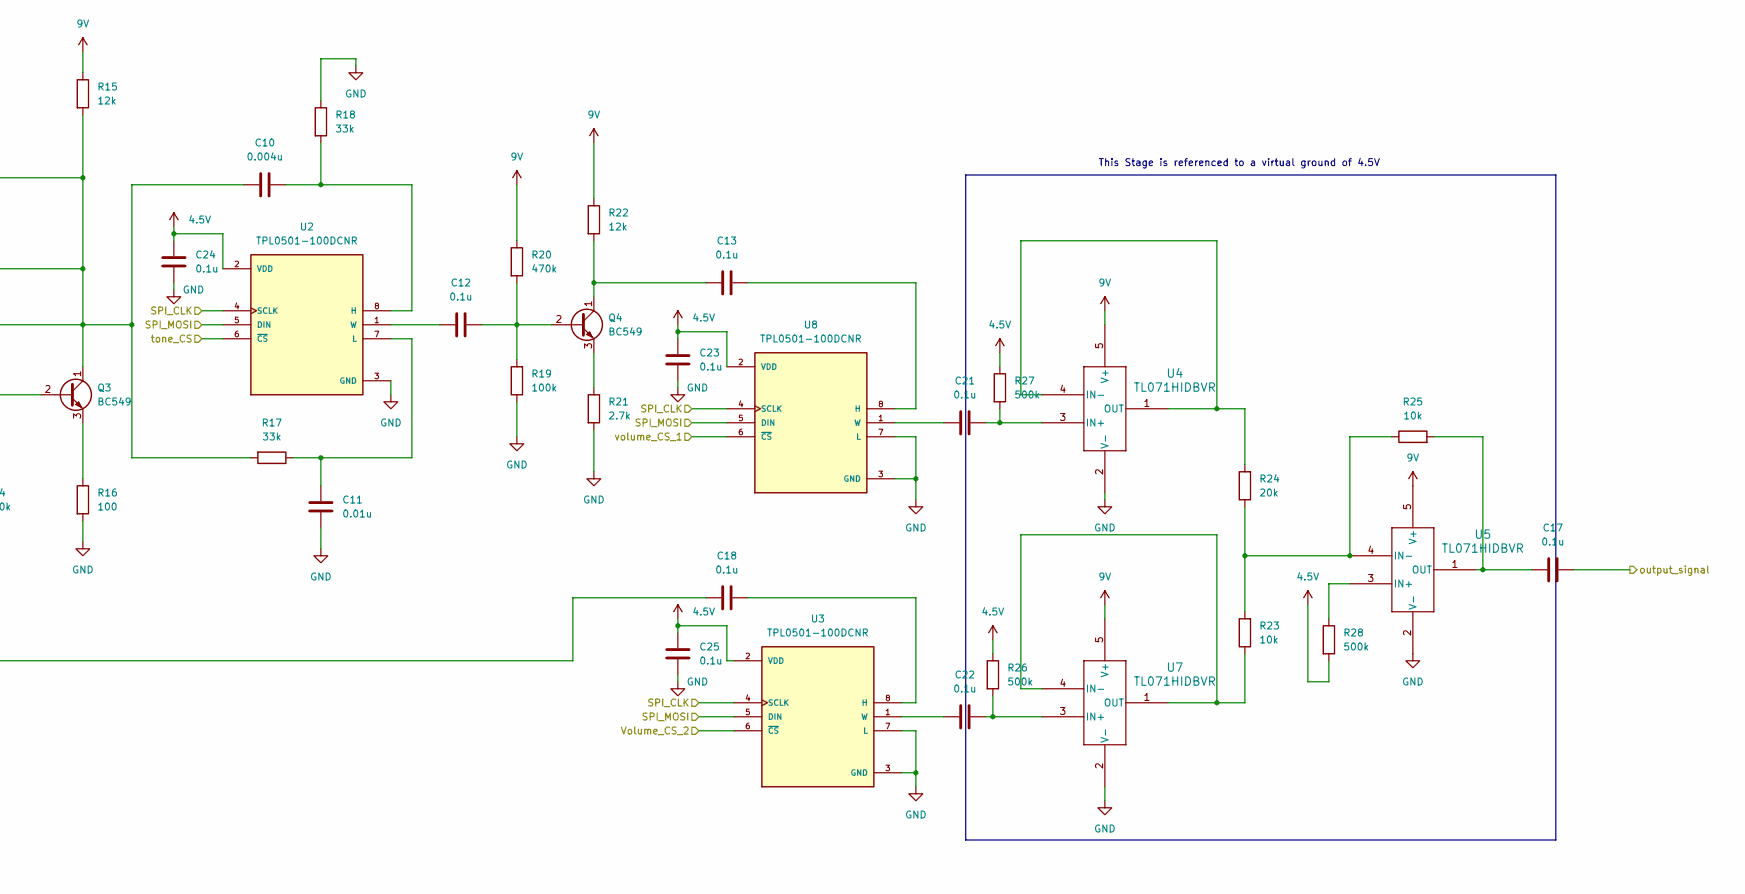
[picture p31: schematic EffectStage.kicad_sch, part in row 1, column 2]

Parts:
C1, C3, C4, C6, C7, C8, C12, C13, C17, C18, C21, C22, C23, C24, C25, C26: 0.1u; C_0603_1608Metric
C2, C5, C9: 470p; C_0603_1608Metric
C10: 0.004u; C_0603_1608Metric
C11: 0.01u; C_0603_1608Metric
C16, C27: 22u; C_0603_1608Metric
C28, C29, C30, C31: 1u; C_0603_1608Metric
CR3, CR4: 1N4148W-13-F; SOD123_DIO
Q1, Q2, Q3, Q4: BC549; TO-92_Inline
R1, R17, R18: 33k; R_0603_1608Metric
R2, R9, R14, R19: 100k; R_0603_1608Metric
R3, R11, R13, R20: 470k; R_0603_1608Metric
R4, R8: 8.2k; R_0603_1608Metric
R5, R12, R15, R22: 12k; R_0603_1608Metric
R6, R10, R16: 100; R_0603_1608Metric
R7: 560; R_0603_1608Metric
R21: 2.7k; R_0603_1608Metric
R23, R25: 10k; R_0603_1608Metric
R24: 20k; R_0603_1608Metric
R26, R27, R28, R29: 500k; R_0603_1608Metric
U1, U2, U3, U8: TPL0501-100DCNR; SOT65P280X145-8N; PARTREV C
U4, U5, U7, U9: TL071HIDBVR; SOT23_DBV_5_TEX

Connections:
4.5V: C23.1, C24.1, C25.1, C26.1, R26.1, R27.1, R28.2, R29.1, U1.2 (VDD), U2.2 (VDD), U3.2 (VDD), U8.2 (VDD); also elsewhere on the board
9V: C28.1, C29.1, C30.1, C31.1, R5.1, R12.1, R15.1, R20.1, R22.1, U4.5 (V+), U5.5 (V+), U7.5 (V+), U9.5 (V+); also elsewhere on the board
/CS0: U8.6 (~CS); also elsewhere on the board
/CS1: U2.6 (~CS); also elsewhere on the board
/CS2: U1.6 (~CS); also elsewhere on the board
/CS3: U3.6 (~CS); also elsewhere on the board
/GUITAR_IN: C27.1; also elsewhere on the board
/GUITAR_OUT: C17.1; also elsewhere on the board
/MOSI: U1.5 (DIN), U2.5 (DIN), U3.5 (DIN), U8.5 (DIN); also elsewhere on the board
/SPI_CLK: U1.4 (SCLK), U2.4 (SCLK), U3.4 (SCLK), U8.4 (SCLK); also elsewhere on the board
GND: C11.2, C23.2, C24.2, C25.2, C26.2, C28.2, C29.2, C30.2, C31.2, R2.2, R6.2, R7.2, R9.2, R10.2, R14.2, R16.2, R18.1, R19.1, R21.2, U1.3 (GND), U2.3 (GND), U3.3 (GND), U3.7 (L), U4.2 (V-), U5.2 (V-), U7.2 (V-), U8.3 (GND), U8.7 (L), U9.2 (V-); also elsewhere on the board
unnamed: C1.2, R1.2
unnamed: C4.1, R8.1
unnamed: C6.1, CR3.2, CR4.1
unnamed: C7.1, R4.1
unnamed: C16.2, C18.2, R1.1
unnamed: C1.1, C2.2, Q1.2 (B), R2.1, R3.1
unnamed: C2.1, C3.2, Q1.1 (C), R3.2, R5.2
unnamed: Q1.3 (E), R6.1
unnamed: C5.2, C6.2, Q2.2 (B), R8.2, R9.1, R11.2
unnamed: C5.1, C7.2, CR3.1, CR4.2, Q2.1 (C), R11.1, R12.2
unnamed: Q2.3 (E), R10.1
unnamed: C8.2, C9.2, Q3.2 (B), R4.2, R13.2, R14.1
unnamed: C8.1, C9.1, C10.2, Q3.1 (C), R13.1, R15.2, R17.2
unnamed: Q3.3 (E), R16.1
unnamed: C12.1, Q4.2 (B), R19.2, R20.2
unnamed: C13.2, Q4.1 (C), R22.2
unnamed: Q4.3 (E), R21.1
unnamed: C3.1, U1.8 (H)
unnamed: R7.1, U1.7 (L)
unnamed: C4.2, U1.1 (W)
unnamed: C10.1, R18.2, U2.8 (H)
unnamed: C11.1, R17.1, U2.7 (L)
unnamed: C12.2, U2.1 (W)
unnamed: C18.1, U3.8 (H)
unnamed: C22.1, U3.1 (W)
unnamed: C21.2, R27.2, U4.3 (IN+)
unnamed: R24.2, U4.1 (OUT), U4.4 (IN-)
unnamed: R28.1, U5.3 (IN+)
unnamed: R23.2, R24.1, R25.1, U5.4 (IN-)
unnamed: C17.2, R25.2, U5.1 (OUT)
unnamed: C22.2, R26.2, U7.3 (IN+)
unnamed: R23.1, U7.1 (OUT), U7.4 (IN-)
unnamed: C13.1, U8.8 (H)
unnamed: C21.1, U8.1 (W)
unnamed: C27.2, R29.2, U9.3 (IN+)
unnamed: C16.1, U9.1 (OUT), U9.4 (IN-)

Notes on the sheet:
This Stage is referenced to a virtual ground of 4.5V
Caps for Op-Amps

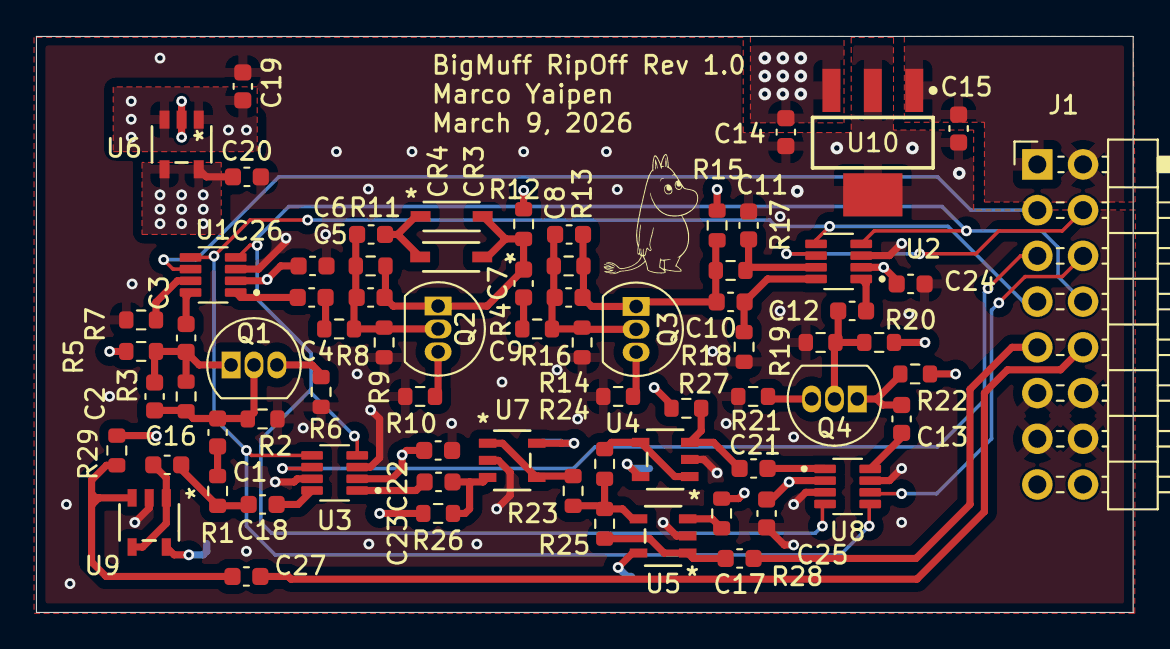
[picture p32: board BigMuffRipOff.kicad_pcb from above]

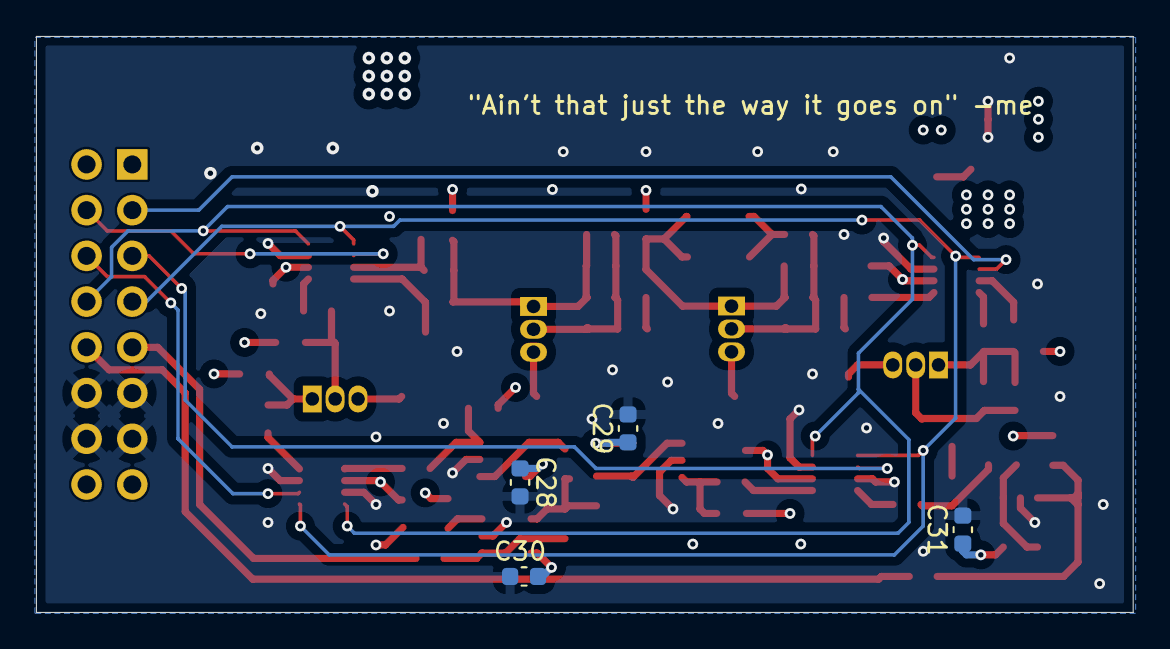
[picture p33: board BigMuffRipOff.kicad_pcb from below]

Board: 4 copper layers, 60.9 x 32.0 mm, 77 parts (4 on the bottom side), 48 nets.

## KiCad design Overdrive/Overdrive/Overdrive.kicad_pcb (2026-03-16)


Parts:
C1, C2: 2.2u; C_0603_1608Metric
C3, C6, C9, C11, C12, C13, C14, C15: 1u; C_0603_1608Metric
C4, C7, C10: 22u; C_0603_1608Metric
C5: 100u; C_1206_3216Metric
C8: 0.3u; C_0603_1608Metric
D1, D2, D3, D4, D5: 1N4148W; D_SOD-123
J1: Conn_02x08_Odd_Even; PinHeader_2x08_P2.54mm_Horizontal
Q1, Q2: 2N3904; TO-92_Inline
R1, R2, R5: 10k; R_0603_1608Metric
R3: 1M; R_0603_1608Metric
R4, R10: 1k; R_0603_1608Metric
R6: 100k; R_0603_1608Metric
R7: 130k; R_0603_1608Metric
R8: 18k; R_0603_1608Metric
R9: 100; R_0603_1608Metric
R11: 40k; R_0603_1608Metric
R12: 36k; R_0603_1608Metric
R13: 6.2k; R_0603_1608Metric
R14: 9k; R_0603_1608Metric
U1, U3, U6: TL071HIDBVR
U2: AD5160; SOT-23-8
U4: ADP7118AUJZ-4.5-R7; UJ-5_ADI
U5: AD8400ARZ1; R_8_ADI

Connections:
5V: C2.1, C14.2, C15.2, U2.2 (V_{DD}), U4.4 (SENSE), U4.5 (VOUT), U5.6 (VDD)
6V: C9.2, R3.1, U1.3 (IN+), U6.4 (IN-)
12V: C1.1, C11.2, C12.2, C13.2, J1.1, J1.2, R1.1, R7.2, R11.2, R13.2, U1.5 (V+), U3.5 (V+), U4.1 (VIN), U4.3 (EN), U6.5 (V+)
/CS0: J1.6, U5.3 (CS*)
/CS2: J1.3, U2.6 (~CS)
/GUITAR_IN: C9.1, J1.10
/GUITAR_OUT: J1.9, U5.7 (W1)
/MOSI: J1.7, U2.5 (SDI), U5.4 (SDI)
/SPI_CLK: J1.8, U2.4 (CLK), U5.5 (CLK)
GND: C1.2, C2.2, C5.1, C6.1, C8.1, C11.1, C12.1, C13.1, C14.1, C15.1, D5.2 (A), J1.11, J1.12, J1.13, J1.14, R2.2, R4.2, R8.1, R10.1, R12.1, U1.2 (V-), U2.3 (GND), U3.2 (V-), U4.2 (GND), U5.1 (B1), U5.2 (GND), U6.2 (V-)
unnamed: C3.2, R5.1
unnamed: C5.2, R9.1, R10.2
unnamed: D1.2 (A), D2.1 (K)
unnamed: C7.2, C8.2, D1.1 (K), R14.2
unnamed: D2.2 (A), D3.1 (K)
unnamed: D3.2 (A), D4.1 (K)
unnamed: D4.2 (A), D5.1 (K)
unnamed: C4.2, Q1.2 (B), R7.1, R8.2
unnamed: Q1.3 (C), Q2.1 (E)
unnamed: Q1.1 (E), R9.2
unnamed: C6.2, Q2.2 (B), R11.1, R12.2
unnamed: C7.1, Q2.3 (C), R13.1
unnamed: R1.2, R2.1, R3.2
unnamed: C10.2, U1.1 (OUT), U1.4 (IN-)
unnamed: C10.1, U2.8 (A)
unnamed: R4.1, U2.7 (B)
unnamed: C3.1, U2.1 (W)
unnamed: R6.1, U3.3 (IN+), U6.1 (OUT)
unnamed: C4.1, U3.1 (OUT), U3.4 (IN-)
unnamed: R14.1, U5.8 (A1)
unnamed: R5.2, R6.2, U6.3 (IN+)

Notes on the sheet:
Volume
Connector to Analog Controller
12 to 3.3 Converter
This resistor is 9.0k instead of 9.5k on the hand-drawn schematic because there are no digital 500 ohm pots only 1k digital pots
Gain
Overdrive Pedal
KiCad Power Flags for ERC
Caps for Op-Amps and Pots


Board: 4 copper layers, 51.5 x 32.0 mm, 43 parts (0 on the bottom side), 31 nets.

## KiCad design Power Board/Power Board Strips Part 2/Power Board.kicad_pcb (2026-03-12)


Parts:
F1: Fuse; Fuseholder_Blade_Mini_Keystone_3568
H1, H2, H3, H4: No. 8; MountingHole_3.2mm_M3
J1: MINIFIT-2-VERT; Molex_Mega-Fit_76829-0102_2x01_P5.70mm_Vertical
J2, J3, J7, J9: MINIFIT-2-VERT; Molex_Mini-Fit_Jr_5566-02A_2x01_P4.20mm_Vertical
J6: Molex_Mega-Fit_76829-0004_2x02_P5.70mm_Vertical
PS1: IRM-60-12; Converter_ACDC_MeanWell_IRM-60-xx_THT
U1: AC025-D24; AC025-D15

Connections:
+12V: F1.2, J2.2, J3.2, J7.2, J9.2
+24V: J6.4, U1.6 (+Vo)
-24V: J6.3, U1.4 (-Vo)
GND: J2.1, J3.1, J6.1, J6.2, J7.1, J9.1, PS1.4 (-Vout), U1.5 (Com)
unnamed: F1.1, J1.2
unnamed: J1.1, PS1.3 (+Vout)

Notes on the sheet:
AC to 12V DC converter
Connector to panel power switchz
^We need to buy one of these, wall mounted
Connector for 12V LV bus

Board: 4 copper layers, 13 parts (0 on the bottom side), 6 nets, no tracks yet.

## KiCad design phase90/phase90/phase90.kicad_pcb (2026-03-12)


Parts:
C2, C4, C6, C7, C8, C9: 0.1u; C_0603_1608Metric
C3, C10, C11, C12, C13, C14: 1u; C_0603_1608Metric
C5: 100u; C_0603_1608Metric
J1: Conn_02x08_Odd_Even; PinHeader_2x08_P2.54mm_Horizontal
Q1, Q2, Q3, Q4: Q_NJFET_DSG; TO-92
R1, R2, R37, R39, R40: 10k; R_0603_1608Metric
R3, R41: 1M; R_0603_1608Metric
R15, R19, R20, R24, R25, R29, R30, R34: 1k; R_0603_1608Metric
R16, R22, R27, R32: 6.2k; R_0603_1608Metric
R17, R18, R21, R23, R26, R28, R31, R33: 510; R_0603_1608Metric
R35, R36: 20k; R_0603_1608Metric
U3, U7, U8, U9, U10, U11: TL071HIDBVR; SOT-23-5

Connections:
6V: C5.2, R3.2, U3.3 (IN+)
12V: C3.1, C10.1, C11.1, C12.1, C13.1, C14.1, J1.1, J1.2, R1.1, R17.1, R21.1, R26.1, R31.1, R39.1, U3.5 (V+), U7.5 (V+), U8.5 (V+), U9.5 (V+), U10.5 (V+), U11.5 (V+); also elsewhere on the board
/CS0: J1.6; also elsewhere on the board
/GUITAR_IN: C2.2, C5.1, J1.10
/GUITAR_OUT: C9.2, J1.9
/MOSI: J1.7; also elsewhere on the board
/Oscillator/Oscillator: Q1.3 (G), Q2.3 (G), Q3.3 (G), Q4.3 (G); also elsewhere on the board
/SPI_CLK: J1.8; also elsewhere on the board
GND: C3.2, C10.2, C11.2, C12.2, C13.2, C14.2, J1.11, J1.12, J1.13, J1.14, R2.2, R18.2, R23.2, R28.2, R33.2, R40.2, U3.2 (V-), U7.2 (V-), U8.2 (V-), U9.2 (V-), U10.2 (V-), U11.2 (V-); also elsewhere on the board
unnamed: C2.1, R35.2
unnamed: C4.2, Q1.1 (D), R16.2, U7.3 (IN+)
unnamed: Q1.2 (S), R16.1, R17.2, R18.1
unnamed: C6.2, Q2.1 (D), R22.2, U8.3 (IN+)
unnamed: Q2.2 (S), R21.2, R22.1, R23.1
unnamed: C7.2, Q3.1 (D), R27.2, U9.3 (IN+)
unnamed: Q3.2 (S), R26.2, R27.1, R28.1
unnamed: C8.2, Q4.1 (D), R32.2, U10.3 (IN+)
unnamed: Q4.2 (S), R31.2, R32.1, R33.1
unnamed: R1.2, R2.1, R3.1
unnamed: R39.2, R40.1, R41.1
unnamed: C4.1, R15.1, U3.1 (OUT), U3.4 (IN-)
unnamed: R15.2, R19.1, U7.4 (IN-)
unnamed: C6.1, R19.2, R20.1, U7.1 (OUT)
unnamed: R20.2, R24.1, U8.4 (IN-)
unnamed: C7.1, R24.2, R25.1, U8.1 (OUT)
unnamed: R25.2, R29.1, U9.4 (IN-)
unnamed: C8.1, R29.2, R30.1, U9.1 (OUT)
unnamed: R30.2, R34.1, U10.4 (IN-)
unnamed: R34.2, R36.2, U10.1 (OUT)
unnamed: R41.2, U11.3 (IN+)
unnamed: R35.1, R36.1, R37.2, U11.4 (IN-)
unnamed: C9.1, R37.1, U11.1 (OUT)

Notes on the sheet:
KiCad Power Flags for ERC
Caps for Op-Amps
6V also contains guitar input because of pullup in beginning
Phase Shift and Sum
6V bus
Connector to Analog Controller


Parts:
C1: 0.82u; C_0603_1608Metric
C15, C16, C17, C18: 1u; C_0603_1608Metric
R4, R38: 2k; R_0603_1608Metric
R5: 3k; R_0603_1608Metric
R6: 150k; R_0603_1608Metric
R7, R8: 10k; R_0603_1608Metric
R9: 1M; R_0603_1608Metric
R10: 9k; R_0603_1608Metric
R11: 15k; R_0603_1608Metric
R12, R13: 1k; R_0603_1608Metric
R14: 2.4k; R_0603_1608Metric
U1, U2, U5, U6: TL071HIDBVR; SOT-23-5
U12: AD5290; MSOP-10_3x3mm_P0.5mm

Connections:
6V oscillator: R9.2, U1.4 (IN-), U2.3 (IN+), U6.3 (IN+)
12V: C15.1, C16.1, C17.1, C18.1, R7.1, R10.1, U1.5 (V+), U2.5 (V+), U5.5 (V+), U6.5 (V+), U12.9 (V_{DD}); also elsewhere on the board
/CS0: U12.5 (~CS); also elsewhere on the board
/MOSI: U12.7 (SDI); also elsewhere on the board
/Oscillator/Oscillator: R13.1, U6.1 (OUT); also elsewhere on the board
/SPI_CLK: U12.6 (CLK); also elsewhere on the board
GND: C15.2, C16.2, C17.2, C18.2, R8.2, R11.1, U1.2 (V-), U2.2 (V-), U5.2 (V-), U6.2 (V-), U12.3 (V_{SS}), U12.4 (GND); also elsewhere on the board
unnamed: R7.2, R8.1, R9.1
unnamed: R4.2, R5.1, U1.3 (IN+)
unnamed: R6.1, R38.2, U1.1 (OUT), U12.2 (B), U12.10 (W)
unnamed: C1.1, R6.2, U2.4 (IN-)
unnamed: C1.2, R4.1, R14.2, U2.1 (OUT)
unnamed: R10.2, R11.2, U5.3 (IN+)
unnamed: R12.2, U5.1 (OUT), U5.4 (IN-)
unnamed: R12.1, R13.2, R14.1, U6.4 (IN-)
unnamed: R5.2, R38.1, U12.1 (A)

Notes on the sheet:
Triangle Wave Oscillator
6V oscillator bus
Caps for Op-Amps
50k in parallel with 2k to get 3k Needed pot that could do "high voltage" analog (larger than up to 5 V since all of these signals are shifted up to 6V as virtual ground)



Board: 4 copper layers, 58.4 x 32.0 mm, 75 parts (10 on the bottom side), 42 nets.

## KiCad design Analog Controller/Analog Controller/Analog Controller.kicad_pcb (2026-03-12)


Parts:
C1: 0.1u; R_0603_1608Metric_Pad0.98x0.95mm_HandSolder
C2: 1u; C_0603_1608Metric
C4, C5, C6, C7, C8, C9, C10, C11, C12, C13, C14, C15, C16, C17, C18: 100n; R_0603_1608Metric_Pad0.98x0.95mm_HandSolder
D1, D2: G; LED_0603_1608Metric_Pad1.05x0.95mm_HandSolder
D3, D4, D5: G; LED_0603_1608Metric_Pad1.05x0.95mm_HandSolder; not fitted
H1, H2, H3, H4: No. 8; MountingHole_3.2mm_M3
J1, J4: MINIFIT-2-VERT; Molex_Mini-Fit_Jr_5566-02A_2x01_P4.20mm_Vertical
J2, J3, J8: Conn_02x08_Counter_Clockwise; PinSocket_2x08_P2.54mm_Vertical
J6: MINIFIT-2-VERT; Molex_Mega-Fit_76829-0102_2x01_P5.70mm_Vertical
J7: Conn_02x09_Counter_Clockwise; Molex_Micro-Fit_3.0_43045-1812_2x09_P3.00mm_Vertical
R1, R2, R3: 27k; R_0603_1608Metric_Pad0.98x0.95mm_HandSolder
R4, R11, R12, R13: 440; R_0603_1608Metric_Pad0.98x0.95mm_HandSolder
R5: 1.2k; R_0603_1608Metric_Pad0.98x0.95mm_HandSolder
R6, R7, R8: 4.7k; R_0603_1608Metric_Pad0.98x0.95mm_HandSolder
R9: 240; R_0603_1608Metric_Pad0.98x0.95mm_HandSolder
RV1, RV2, RV3: R_Potentiometer_US; not fitted
SW1: SW_SPDT; not fitted
SW3: SW_Push_Open; not fitted
U1, U2, U3, U6, U7, U8: TS12A12511DCNR; DCN8
U4: R-78C3.3-1.0; Converter_DCDC_RECOM_R-78E-0.5_THT
U5: TMA-1205D; Converter_DCDC_TRACO_TMA-05xxD_12xxD_Dual_THT
U11, U12, U13: 74LVC1G17; SOT-23-5

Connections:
+3V3: C16.1, C17.1, C18.1, R4.2, R6.1, R7.1, R8.1, U4.3 (OUT), U11.5 (VCC), U12.5 (VCC), U13.5 (VCC); also elsewhere on the board
+5V: C4.1, C6.1, C8.1, C10.1, C12.1, C14.1, U1.4 (V+), U2.4 (V+), U3.4 (V+), U5.6 (+Vout), U6.4 (V+), U7.4 (V+), U8.4 (V+)
+12V: J2.1, J2.2, J3.1, J3.2, J6.2, J8.1, J8.2, R1.1, R2.1, R3.1, R5.2, U4.1 (IN), U5.1 (+Vin)
-5V: C5.1, C7.1, C9.1, C11.1, C13.1, C15.1, U1.7 (V-), U2.7 (V-), U3.7 (V-), U5.4 (-Vout), U6.7 (V-), U7.7 (V-), U8.7 (V-)
/CS_0: J3.6; also elsewhere on the board
/CS_1: J3.4; also elsewhere on the board
/CS_2: J3.3; also elsewhere on the board
/CS_3: J3.5; also elsewhere on the board
/CS_4: J2.6; also elsewhere on the board
/CS_5: J2.4; also elsewhere on the board
/CS_6: J2.3; also elsewhere on the board
/CS_7: J2.5; also elsewhere on the board
/CS_8: J8.6; also elsewhere on the board
/CS_9: J8.4; also elsewhere on the board
/CS_10: J8.5; also elsewhere on the board
/CS_11: J8.3; also elsewhere on the board
/ES_0: J7.6, R7.2, SW1.1 (A); also elsewhere on the board
/ES_1: J7.5, R8.2, SW1.3 (C); also elsewhere on the board
/From_Preamp: C2.1, J1.2
/LED_0: U11.2; also elsewhere on the board
/LED_1: U12.2; also elsewhere on the board
/LED_2: U13.2; also elsewhere on the board
/LED_OUT_0: D3.2 (A), J7.1, R11.1
/LED_OUT_1: D4.2 (A), J7.2, R12.1
/LED_OUT_2: D5.2 (A), J7.3, R13.1
/MOSI: J2.7, J3.7, J8.7; also elsewhere on the board
/POT_0: J7.7, R1.2, RV1.1; also elsewhere on the board
/POT_1: J7.8, R2.2, RV2.1; also elsewhere on the board
/POT_2: J7.9, R3.2, RV3.1; also elsewhere on the board
/SPDT_0: U1.6 (IN), U2.6 (IN); also elsewhere on the board
/SPDT_1: U3.6 (IN), U6.6 (IN); also elsewhere on the board
/SPDT_2: U7.6 (IN), U8.6 (IN); also elsewhere on the board
/SPI_CLK: J2.8, J3.8, J8.8; also elsewhere on the board
/To_Dig_Board: C1.1, J4.2, R9.1
/Toggle_ON/OFF: J7.4, R6.2, SW3.1 (A); also elsewhere on the board
From_Analog_1: J3.9, U2.8 (NO)
From_Analog_2: J2.9, U6.8 (NO)
From_Analog_3: J8.9, U8.8 (NO)
GND: C1.2, C4.2, C5.2, C6.2, C7.2, C8.2, C9.2, C10.2, C11.2, C12.2, C13.2, C14.2, C15.2, C16.2, C17.2, C18.2, D1.1 (K), D2.1 (K), J1.1, J2.11, J2.12, J2.13, J2.14, J3.11, J3.12, J3.13, J3.14, J4.1, J6.1, J7.10, J7.11, J7.12, J7.13, J7.14, J7.15, J7.16, J7.17, J7.18, J8.11, J8.12, J8.13, J8.14, U1.3 (GND), U2.3 (GND), U3.3 (GND), U4.2 (GND), U5.2 (-Vin), U5.5 (Com), U6.3 (GND), U7.3 (GND), U8.3 (GND), U11.3 (GND), U12.3 (GND), U13.3 (GND); also elsewhere on the board
unnamed: D1.2 (A), R4.1
unnamed: D2.2 (A), R5.1
unnamed: R11.2, U11.4
unnamed: R12.2, U12.4
unnamed: R13.2, U13.4
unnamed: C2.2, U1.1 (COM)
unnamed: U1.2 (NC), U2.2 (NC)
unnamed: U2.1 (COM), U3.1 (COM)
unnamed: U3.2 (NC), U6.2 (NC)
unnamed: U6.1 (COM), U7.1 (COM)
unnamed: U7.2 (NC), U8.2 (NC)
unnamed: R9.2, U8.1 (COM)
To_Analog_1: J3.10, U1.8 (NO)
To_Analog_2: J2.10, U3.8 (NO)
To_Analog_3: J8.10, U7.8 (NO)

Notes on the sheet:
LEDs
For SPDT: Reads 0V or 3V3
Connectors for Front Panel Signals
Schmitt Trigger
STM Microcontroller
For Pot: Potentiometer = 0 ohm - 10k ohm When pot is 0 ohms, ADC reads 0V When pot is 10k ohms, ADC reads 3.2V
Board to Board Connectors for Analog Effects
Power
Single Pole Double Throw Switches

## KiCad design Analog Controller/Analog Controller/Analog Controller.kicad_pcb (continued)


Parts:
C21: 10u; R_0603_1608Metric_Pad0.98x0.95mm_HandSolder
C22, C23, C24, C25, C28, C29: 0.1u; R_0603_1608Metric_Pad0.98x0.95mm_HandSolder
C26: 10n; R_0603_1608Metric_Pad0.98x0.95mm_HandSolder
C27, C30: 1u; R_0603_1608Metric_Pad0.98x0.95mm_HandSolder
J10: TC2050; Tag-Connect_TC2050-IDC-FP_2x05_P1.27mm_Vertical
R14, R15, R16, R17, R18, R19, R20, R21, R23: 150; R_0603_1608Metric_Pad0.98x0.95mm_HandSolder
R22: 10k; R_0603_1608Metric_Pad0.98x0.95mm_HandSolder
SW2: SW_Omron_B3FS; SW_SPST_Omron_B3FS-101xP
SW4: SW_SPST; SW_SPST_B3U-1000P
U14: STM32G474RETx; LQFP-64_10x10mm_P0.5mm

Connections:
+3V3: C21.1, C22.1, C23.1, C24.1, C25.1, C26.1, C27.1, R16.1, SW4.1 (A), U14.1 (VBAT), U14.16 (VDD), U14.29 (VDDA), U14.32 (VDD), U14.48 (VDD), U14.64 (VDD); also elsewhere on the board
/CS_0: U14.9 (PC1); also elsewhere on the board
/CS_1: U14.10 (PC2); also elsewhere on the board
/CS_2: U14.11 (PC3); also elsewhere on the board
/CS_3: U14.12 (PA0); also elsewhere on the board
/CS_4: U14.14 (PA2); also elsewhere on the board
/CS_5: U14.22 (PC4); also elsewhere on the board
/CS_6: U14.23 (PC5); also elsewhere on the board
/CS_7: U14.24 (PB0); also elsewhere on the board
/CS_8: U14.26 (PB2); also elsewhere on the board
/CS_9: U14.33 (PB11); also elsewhere on the board
/CS_10: U14.30 (PB10); also elsewhere on the board
/CS_11: U14.34 (PB12); also elsewhere on the board
/ES_0: U14.41 (PC9); also elsewhere on the board
/ES_1: U14.40 (PC8); also elsewhere on the board
/LED_0: U14.36 (PB14); also elsewhere on the board
/LED_1: U14.37 (PB15); also elsewhere on the board
/LED_2: U14.38 (PC6); also elsewhere on the board
/MOSI: U14.21 (PA7); also elsewhere on the board
/POT_0: U14.35 (PB13); also elsewhere on the board
/POT_1: U14.42 (PA8); also elsewhere on the board
/POT_2: U14.43 (PA9); also elsewhere on the board
/SPDT_0: U14.8 (PC0); also elsewhere on the board
/SPDT_1: U14.13 (PA1); also elsewhere on the board
/SPDT_2: U14.25 (PB1); also elsewhere on the board
/SPI_CLK: U14.19 (PA5); also elsewhere on the board
/STM32_MCU/BOOT0: R22.2, R23.2, U14.61 (PB8)
/STM32_MCU/NRST: C28.1, R21.2, SW2.2, U14.7 (PG10)
/STM32_MCU/SWCLK: R20.2, U14.50 (PA14)
/STM32_MCU/SWDIO: R19.2, U14.49 (PA13)
/STM32_MCU/USART1_RX(MCU): R14.1, U14.60 (PB7)
/STM32_MCU/USART1_TX(MCU): R15.1, U14.59 (PB6)
/Toggle_ON/OFF: U14.39 (PC7); also elsewhere on the board
GND: C21.2, C22.2, C23.2, C24.2, C25.2, C26.2, C27.2, C28.2, C29.2, C30.2, R17.1, R18.2, R22.1, SW2.1, U14.15 (VSS), U14.27 (VSSA), U14.31 (VSS), U14.47 (VSS), U14.63 (VSS); also elsewhere on the board
unnamed: J10.1, R14.2
unnamed: J10.2, R15.2
unnamed: J10.4, R16.2
unnamed: J10.5, R17.2
unnamed: J10.6, R21.1
unnamed: J10.7, R20.1
unnamed: J10.8, R19.1
unnamed: J10.9, J10.10, R18.1
unnamed: R23.1, SW4.2 (B)
unnamed: C29.1, C30.1, U14.28 (VREF+)

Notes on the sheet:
GPIO



Board: 4 copper layers, 76.2 x 71.1 mm, 77 parts (4 on the bottom side), 70 nets.

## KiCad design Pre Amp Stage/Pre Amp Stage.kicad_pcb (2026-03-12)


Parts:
C1: 68p; R_0603_1608Metric
C2, C7: 10u; R_0603_1608Metric
C3: 47n; R_0603_1608Metric
C4: 940p; R_0603_1608Metric
C5: 0.0047u; R_0603_1608Metric
C6: 680p; R_0603_1608Metric
C8, C9, C10, C11, C13, C14: 1u; R_0603_1608Metric
C12: 220p; R_0603_1608Metric
C15: 100u; R_0805_2012Metric_Pad1.20x1.40mm_HandSolder
H1, H2, H3, H4: MountingHole; MountingHole_2.2mm_M2
J1: NMJ6HFD2; Jack_6.35mm_Neutrik_NMJ6HFD2_Horizontal
J2, J3, J5, J6, J7: Conn_01x03; Molex_Micro-Fit_3.0_43650-0315_1x03_P3.00mm_Vertical
J4, J8: MINIFIT-2-VERT; Molex_Mini-Fit_Jr_5566-02A_2x01_P4.20mm_Vertical
Q1: Q_NJFET_DSG; TO-92_Inline
R1: 499k; R_0603_1608Metric
R2: 100; R_0603_1608Metric
R3: 50k; R_0603_1608Metric
R4, R6, R7, R9: 7.5k; R_0603_1608Metric
R5, R8: 2.7k; R_0603_1608Metric
R10, R11: 100k; R_0603_1608Metric
U1, U3, U4: TL071HIDBVR; TL071
U2: TMA-1215D; Converter_DCDC_TRACO_TMA-05xxD_12xxD_Dual_THT

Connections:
+12V: C7.1, J4.2, U2.1 (+Vin)
+15V: C8.1, C9.1, C13.1, J2.2, J2.3, U1.5 (V+), U2.6 (+Vout), U3.5 (V+), U4.5 (V+)
-15V: C10.1, C11.1, C14.1, U1.2 (V-), U2.4 (-Vout), U3.2 (V-), U4.2 (V-)
GND: C1.2, C7.2, C8.2, C9.2, C10.2, C11.2, C12.2, C13.2, C14.2, J1.R, J1.RN, J1.S, J1.SN, J1.TN, J3.1, J4.1, J8.1, R1.2, R2.2, U2.2 (-Vin), U2.5 (Com), U3.3 (IN+)
unnamed: C3.2, R3.1
unnamed: C5.1, R10.2, R11.2
unnamed: C15.2, J8.2
unnamed: C3.1, J2.1, Q1.1 (D)
unnamed: J3.2, U1.3 (IN+)
unnamed: J3.3, R3.2
unnamed: J5.1, R4.2
unnamed: J5.2, R10.1
unnamed: J5.3, R7.1
unnamed: C4.2, J6.1, R5.2
unnamed: C5.2, J6.2
unnamed: C4.1, J6.3, R8.1
unnamed: J7.1, R6.2
unnamed: C6.2, J7.2
unnamed: J7.3, R9.1
unnamed: C2.2, C12.1, Q1.3 (G), R1.1
unnamed: Q1.2 (S), R2.1
unnamed: R4.1, R5.1, R6.1, U1.1 (OUT), U1.4 (IN-)
unnamed: C6.1, R11.1, U3.4 (IN-)
unnamed: C15.1, R7.2, R8.2, R9.2, U3.1 (OUT)
unnamed: J1.T, U4.3 (IN+)
unnamed: C1.1, C2.1, U4.1 (OUT), U4.4 (IN-)

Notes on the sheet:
50k Pot Bass
Gain 5k potentiometer on panel
Connector for 12V LV bus
Volume 100k potentiometer on panel
50k Pot Treble
50k Pot Midrange



Board: 4 copper layers, 76.2 x 40.6 mm, 43 parts (2 on the bottom side), 26 nets.

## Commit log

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2026-01-23 fixed 5 silkscreens
    boo
    [BigMuffRipOff.kicad_pcb]
2026-02-01 datasheet updates
    womp womp
    [BigMuffRipOff.kicad_pcb, BigMuffRipOff.kicad_sch, EffectStage.kicad_sch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]
2026-02-01 starting to redo board layout
    also finished changing the schematic
    [BigMuffRipOff.kicad_pcb, EffectStage.kicad_sch]
2026-02-10 did half of the changes
    gonna finish the next have next time
    [BigMuffRipOff.kicad_pcb, EffectStage.kicad_sch, MCU.kicad_sch]
2026-02-10 getting closer on finishing layout
    [BigMuffRipOff.kicad_pcb, BigMuffRipOff.kicad_sch, EffectStage.kicad_sch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]
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2026-02-14 Initial Commit
    Added Power Board and Analog Controller
    [Analog Controller.kicad_pcb, Analog Controller.kicad_sch, Power Board.kicad_pcb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]
2026-02-15 Finished schematic and layout of power board
    [Power Board.kicad_pcb, Power Board.kicad_sch]
2026-02-15 please dont break plsplspls
    [BigMuffRipOff.kicad_pcb, MCU.kicad_sch]
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2026-02-22 made digital and recording board schematic
    [Connectors.kicad_sch, DR_daisy_seed.kicad_sch, DR_power.kicad_sch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]
2026-02-22 updated schematic to use +/-5 DCDC
    [Connectors.kicad_sch, DR_power.kicad_sch, TMV_1205D.step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]
2026-02-22 added datasheet to new DCDC converter
    [DR_power.kicad_sch]
2026-02-22 look mom i did it
    the board is done
    [BigMuffRipOff.kicad_pcb, EffectStage.kicad_sch]
2026-02-22 modified power for proper amp rating of daisy seed
    [Connectors.kicad_sch, DR_daisy_seed.kicad_sch, DR_power.kicad_sch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]
2026-02-22 added datasheets to new dcdc converters
    [DR_power.kicad_sch]
2026-02-23 layout for digital board is essentially complete
    current draw for the screen may fuck us if it is too high
    [Connectors.kicad_sch, DR_daisy_seed.kicad_sch, DR_power.kicad_sch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]
2026-02-23 Completed Analog Controller Board
    Completed Analog Controller Board schematic and pcb layout :)
    [284697-E.SchLib, 284697E.PcbLib, 284697e.psm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]
2026-02-23 im pushing in case kicad crashes again
    also the board was significantly updated
    [Connectors.kicad_sch, DR_daisy_seed.kicad_sch, digital_and_recording.kicad_pcb]
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2026-02-24 added fun silk screens
    [digital_and_recording.kicad_pcb]
2026-02-24 updated schematic of digital and recording board to use 2 pin molex for power and guitar signals
    [Connectors.kicad_sch, digital_and_recording.kicad_sch]
2026-02-24 corrected connectors
    [Connectors.kicad_sch, digital_and_recording.kicad_pcb]
2026-02-24 whoops forgot this one
    [digital_and_recording.kicad_pcb]
2026-02-25 Reduced minimum clearance on digicorder
    [Analog Controller.kicad_pcb, digital_and_recording.kicad_pcb]
2026-02-26 changes for digital and recording board. pass to marco
    [digital_and_recording.kicad_pcb]
2026-03-04 created kiCad project for overdrive
    [Overdrive.kicad_pcb, Overdrive.kicad_sch]
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2026-03-06 updated datasheet to point to digikey for 1k pot
    [Overdrive.kicad_sch]
2026-03-08 Mostly Finished Power Amp Board
    [Power Amp Board.kicad_pcb, Power Amp Board.kicad_sch]
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2026-03-09 finished schematic for phase 90 and implemented the correct op-amps for overdrive
    [Overdrive.kicad_sch, jfet characterization.xlsx, oscillator.kicad_sch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]
2026-03-09 changed out potentiometer for one that can do higher analog voltages
    [Overdrive.kicad_sch, oscillator.kicad_sch, phase90.kicad_sch]
2026-03-09 new big muff made
    [BigMuffRipOff.kicad_pcb, BigMuffRipOff.kicad_sch, EffectStage.kicad_sch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]
2026-03-09 new big muff completed
    [BigMuffRipOff.kicad_pcb, BigMuffRipOff.kicad_sch, EffectStage.kicad_sch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]
2026-03-09 removed the old diodes from before
    [BigMuffRipOff.kicad_pcb, EffectStage.kicad_sch]
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2026-03-09 updated phase 90 to not need 12 to 3 converted
    [oscillator.kicad_sch]
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2026-03-09 finished board except for silk screen
    [phase90.kicad_pcb, phase90.kicad_sch]
2026-03-10 silks have been scooted
    [phase90.kicad_pcb]
2026-03-10 Added new stm32 microcontroller, redid pcb layout
    [Analog Controller.kicad_pcb, Analog Controller.kicad_sch, stm32_mcu.kicad_sch]
2026-03-10 removed all .DS_Store files and updated .gitignore to no longer have them included in the repo. Also started board reviews
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2026-03-11 connector for big muff updated
    [BigMuffRipOff.kicad_pcb, BigMuffRipOff.kicad_sch]
2026-03-11 updated design rules for OshPark
    [phase90.kicad_pcb]
2026-03-11 big muff connector fixed i think?
    [BigMuffRipOff.kicad_pcb, BigMuffRipOff.kicad_sch, EffectStage.kicad_sch]
2026-03-11 fixed connector also?
    [phase90.kicad_pcb, phase90.kicad_sch]
2026-03-11 power amp design rule changes
    [Power Amp Board.kicad_pcb]
2026-03-11 overdrive updates to conform with new connector
    [Overdrive.kicad_pcb, Overdrive.kicad_sch]
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2026-03-12 Added top copper gnd layer on pre amp
    [Pre Amp Stage.kicad_pcb]
2026-03-12 added buffer to schematic of power amp
    [Power Amp Board.kicad_sch]
2026-03-12 Incorporated changes from demo
    [Analog Controller.kicad_pcb, Analog Controller.kicad_sch, Pre Amp Stage.kicad_pcb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]
2026-03-12 added buffers and caps for op-amps on effect boards
    [Connectors.kicad_sch, Overdrive.kicad_pcb, Overdrive.kicad_sch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]
2026-03-12 just absolutely lapped kyle
    get fucked kyle
    [Power Amp Board.kicad_pcb, Power Amp Board.kicad_sch]
2026-03-12 added buffer to big muff
    [BigMuffRipOff.kicad_pcb, EffectStage.kicad_sch]
2026-03-12 addressed Marco's design review
    [Overdrive.kicad_pcb]
2026-03-12 fixes for Marco's dr
    [Analog Controller.kicad_pcb, Analog Controller.kicad_sch, phase90.kicad_pcb]
2026-03-12 more clearances for power board screw terminals
    [Power Board.kicad_pcb]
2026-03-12 more clearances for pre-amp screw terminals
    [Pre Amp Stage.kicad_pcb]
2026-03-12 i fixed kyles fuckery
    hes the goat tho
    [BigMuffRipOff.kicad_pcb]
2026-03-12 more clearance not thermal reliefs
    [Power Board.kicad_pcb]
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2026-03-12 Power strip board part 1
    [Power Board.kicad_pcb, Power Board.kicad_sch]
2026-03-12 Power strip board part 2
    [Power Board.kicad_pcb, Power Board.kicad_sch]
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2026-03-16 board fixes for Overdrive based off of Joseph's reviews
    [Overdrive.kicad_pcb, Overdrive.kicad_sch]
2026-03-16 made changes for power
    [BigMuffRipOff.kicad_pcb]
2026-03-16 fixed board again
    [Power Amp Board.kicad_pcb, Power Amp Board.kicad_sch]
2026-03-18 fixed usb pitch issue
    [digital_and_recording.kicad_pcb]
2026-03-18 fixed it
    [Connectors.kicad_sch]
2026-03-19 Analog controller and power board BOMs
    [Analog Controller.csv, Power Board BOM.csv]
2026-03-19 pre amp stage bom
    [Analog Controller.csv, Pre Amp Stage.csv]
2026-03-20 created master BOM for all boards
    [Analog Controller.csv, BigMuffRipOff.csv, BigMuffRipOff.kicad_sch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]
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2026-03-25 boms suck man
    added csvs of the digikey cart as well as highlighted the excel
    [capDigikey.csv, capsAndMoreDigikey.csv, master_BOM.xlsx]
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
